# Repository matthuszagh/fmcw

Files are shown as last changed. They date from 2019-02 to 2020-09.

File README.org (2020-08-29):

#+NAME: fig:bridge raw-fft
#+ATTR_ORG: :width 1000
#+ATTR_HTML: :width 100%
[[file:data/bridge_raw.png][file:.img/bridge_raw.png]]

Real-time range detection performed by radar. Distance (y-axis) is in
meters and the time (x-axis) is in seconds. Magnitude is in dBFS
relative to the max ADC input.

* Table of Contents
1. [[https://github.com/matthuszagh/fmcw#about][About]]
2. [[https://github.com/matthuszagh/fmcw#capabilities][Capabilities]]
3. [[https://github.com/matthuszagh/fmcw#installation][Installation]]
4. [[https://github.com/matthuszagh/fmcw#usage][Usage]]
5. [[https://github.com/matthuszagh/fmcw#additional-hardware][Additional Hardware]]
6. [[https://github.com/matthuszagh/fmcw#contributing][Contributing]]
7. [[https://github.com/matthuszagh/fmcw#thanks][Thanks]]

* About
:PROPERTIES:
:ID:       20ff1c28-cfc6-4280-8501-83314fee390d
:END:
This repo includes the custom PCBs, PC control software and FPGA
gateware necessary to build and operate a 6GHz FMCW radar. It also
includes a number of other useful additions, such as RF and SPICE
simulations (in progress) as well as CAD designs for useful additions
(e.g. to build the horn antennas).

The project is a fork of [[https://github.com/Ttl/fmcw3][Henrik's excellent design]]. Although I've made
a number of [[id:8f78da8c-ec0c-40f3-9b8b-6c1af11f4bb2][significant changes]], most of the PCB design (as of this
writing) is still identical to Henrik's. Despite the fact that Henrik
deserves a large share of the credit for this project, he is in no way
affiliated with this fork.

This project is still a work in progress. While [[https://github.com/matthuszagh/fmcw/tree/master/hardware/boards/rev1][rev1]] achieves good
results, the noise floor is higher than it should be. In particular,
this version suffers from an excessively noisy switching
converter. [[https://github.com/matthuszagh/fmcw/tree/master/hardware/boards/rev2][Rev2]] has been designed to fix these issues, but still
requires a few changes before it's ready to be built. In the meantime,
if you're able to track down the power amplifier Henrik used in his
design (it's deprecated, but some people have had luck on Ebay), I
would recommend that over rev1.

* Capabilities
This radar (and associated software) can display the range of remote
objects in real-time out to at least 250m. The radar should be capable
of ranges up to 1km, but this has not yet been tested. The radar code
is also designed to be quite flexible. For instance, you can display
data at any intermediary processing step (including the raw receiver
channel data) without recompiling the FPGA code. All display
configurations support real-time plotting. The many configuration
options can be viewed by invoking the software shell environment (see
[[https://github.com/matthuszagh/fmcw#usage][usage]])

The PCB is capable of angle detection as well, but the associated FPGA
and software code has not yet been written to support this. A future
update will also add an RF switch to multiplex the receiver channels
for better angular resolution.

* Installation
:PROPERTIES:
:ID:       fe23bc7f-9bcf-4526-9d7e-bded4078111d
:END:
Using the radar requires an installation of [[https://sourceforge.net/projects/openocd/][OpenOCD]] (for loading the
bitstream onto the FPGA), [[https://www.intra2net.com/en/developer/libftdi/][libFTDI1]] for communicating between the host
Linux machine and the radar and a Python3 installation including
[[https://numpy.org/][NumPy]], [[https://www.scipy.org/][SciPy]], [[http://www.pyqtgraph.org/][PyQtGraph]], as well as a [[https://cython.org/][Cython compiler]] to compile a
small amount of optimized C code.

Finally, it is necessary to have unprivileged access to the radar in
order to use it. Add the following to ~/etc/udev~ (for instance, in
~/etc/udev/rules.d/99-local.rules~):

#+begin_src txt
# FMCW Radar
ENV{ID_VENDOR_ID}=="0403", ENV{ID_MODEL_ID}=="6010", MODE:="666"
#+end_src

To register the changes, run:

#+begin_src sh
sudo udevadm control --reload-rules && udevadm trigger
#+end_src

** FPGA Bitstream Generation
The FPGA bitstream is updated in this repo whenever the Verilog code
changes. As a result, if you just want to use the radar you should
never need to compile the bitstream yourself. If you do want to modify
the FPGA configuration, you can edit the Verilog source files to your
liking (located in [[https://github.com/matthuszagh/fmcw/tree/master/gateware/verilog/src][gateware/verilog/src]]) and then recompile the
bitstream with ~make bitstream~ in the [[https://github.com/matthuszagh/fmcw/tree/master/gateware/verilog][gateware/verilog]]
directory. This requires an installation of Vivado. I've only tested
this with v2017.2, although it should work with newer versions as
well. If this is not the case please file a bug report.

** Tests and Formal Verification
Verilog functional tests and formal verification can be run from
[[https://github.com/matthuszagh/fmcw/tree/master/gateware/verilog][gateware/verilog]] directory with ~make test~ (for [[https://docs.cocotb.org/en/latest/][Cocotb]] tests), ~make
sim~ for more traditional Verilog testbenches, and ~make formal~ for
formal verification. There are also subtargets for specific
modules. Cocotb tests require an installation of Cocotb and
traditional Verilog testbenches require an installation of [[https://github.com/steveicarus/iverilog][Icarus
Verilog]]. Formal verification requires [[https://github.com/YosysHQ/SymbiYosys][SymbiYosys]], [[https://github.com/YosysHQ/yosys][yosys]], and the [[https://github.com/SRI-CSL/yices2][yices]]
SMT solver.

** Microwave Simulations
Microwave simulations are performed with [[https://openems.de/start/][OpenEMS]], using my own python
interface tool, [[https://github.com/matthuszagh/pyems][pyems]]. These are located in the [[https://github.com/matthuszagh/fmcw/tree/master/simulations/openems][simulations/openems]]
directory and can be run individually.

** Ngspice Simulations
Ngspice simulations are a work-in-progress. Nevertheless, if you'd
like to test them they can be found in the [[https://github.com/matthuszagh/fmcw/tree/master/simulations/ngspice][simulations/ngspice]]
directory and the python files can be run individually. They require
an installation of [[https://github.com/xesscorp/skidl][SKiDL]], [[https://github.com/FabriceSalvaire/PySpice][PySpice]], and, of course, [[http://ngspice.sourceforge.net/][Ngspice]].

** CAD Designs
The antenna mount and horn antenna CAD designs are available in the
[[https://github.com/matthuszagh/fmcw/tree/master/hardware/cad][hardware/cad]] directory. The [[https://www.openscad.org/][OpenSCAD]] source files as well as the
generated STL files are available there. If you only want to 3D print
the objects, the STL files are sufficient. If, however, you'd like to
modify them, you'll need an installation of OpenSCAD (or you can
modify the STL files in another CAD program like FreeCAD).

** PCB Design
The KiCAD PCB design files are located in subdirectories of
[[https://github.com/matthuszagh/fmcw/tree/master/hardware/boards][hardware/boards]]. They require KiCAD to view and modify. The gerbers
are available as zip files here. Note that because rev2 is not yet
complete, those gerbers are not up-to-date. The hardware directory
also contains some projects which are in development, such as an
antenna switch and various prototype boards. These are not, in
general, complete and are thus not recommended for use.

* Usage
When the radar is setup and plugged in, administer power to the PCB,
navigate to the top-level directory and type ~make~. This will program
the bitstream to the FPGA and invoke a custom shell for interacting
with the radar. If everything so far has worked, you will be presented
with the following shell environment:

#+begin_example
Available commands:
----------
conf : Display current configuration.
exit : Exit.
help : This display.
run  : Instantiate the current configuration,
       begin data acquisition, and display output.
set  : Change the value of a configuration
       variable.
menu : Automatically set configuration variables
       based on one of several common tasks.

fmcw >
#+end_example

We can redisplay this menu at any point by typing ~fmcw > help~
(~fmcw >~ is prompted as part of the shell display, so you only need to
type ~help~), and we can exit with ~fmcw > exit~.

The set of possible commands appears in the left column, with their
associated descriptions to the right. All commands can be typed
exactly as displayed, or you can type the minimum number of letters
that uniquely differentiates a menu entry from the other entries. So,
for instance, if I wanted to see the current configuration I could
type ~fmcw > c~ (~conf~ is the only command that begins with the
letter ~c~).

#+begin_example
fmcw > c
Configuration:
----------
FPGA output                 : RAW
display output              : FFT
log file                    : /home/matt/src/fmcw/software
capture time (s)            : 35
plot type                   : HIST
dB min                      : -120.0
dB max                      : -20.0
plot save dir               : /home/matt/src/fmcw/software/plots
subtract last               : True
receiver channel            : B
ADF start frequency (Hz)    : 5600000000.0
ADF bandwidth (Hz)          : 300000000.0
ADF sweep time (s)          : 0.001
ADF delay time (s)          : 0.002
min plotting frequency (Hz) : 0
max plotting frequency (Hz) : 470325
min plotting distance (m)   : 0
max plotting distance (m)   : 235
dist/freq axis              : dist
report average              : False
#+end_example

If I wanted to view, say, a spectrum plot instead of a histogram, I
would start by typing ~fmcw > s~.

This presents the configuration options

#+begin_example
fmcw > set
Set options (enter the corresponding number):
----------
0. FPGA output
1. display output
2. log file
3. capture time (s)
4. plot type
5. dB min
6. dB max
7. plot save dir
8. subtract last
9. receiver channel
10. ADF start frequency (Hz)
11. ADF bandwidth (Hz)
12. ADF sweep time (s)
13. ADF delay time (s)
14. min plotting frequency (Hz)
15. max plotting frequency (Hz)
16. min plotting distance (m)
17. max plotting distance (m)
18. dist/freq axis
19. report average
#+end_example

Since I wanted to change ~plot type~, which is entry 4, I'd type ~set
> 4~,

#+begin_example
set > 4
Parameter       : plot type
Current Value   : HIST
Possible Values : {TIME (except FFT output), SPECTRUM, HIST} (case insensitive)

**Note that when setting selection options (e.g. plot type),
it is only necessary to type the first characters that fully
differentiate the selection from all other choices.
#+end_example

This tells me the available selections for this parameter. Like
before, I'm allowed to just type the first differentiating letters,
which in this case is simpy ~new value > s~

#+begin_example
new value > s
New value set.
#+end_example

which presents a comfirmation that the value has been correctly
set. Indeed, if we redisplay the current configuration, we see that
plot type is now SPECTRUM:

#+begin_example
fmcw > conf
Configuration:
----------
FPGA output                 : RAW
display output              : FFT
log file                    : /home/matt/src/fmcw/software
capture time (s)            : 35
plot type                   : SPECTRUM
dB min                      : -120.0
dB max                      : -20.0
plot save dir               : /home/matt/src/fmcw/software/plots
subtract last               : True
receiver channel            : B
ADF start frequency (Hz)    : 5600000000.0
ADF bandwidth (Hz)          : 300000000.0
ADF sweep time (s)          : 0.001
ADF delay time (s)          : 0.002
min plotting frequency (Hz) : 0
max plotting frequency (Hz) : 470325
min plotting distance (m)   : 0
max plotting distance (m)   : 235
dist/freq axis              : dist
report average              : False
#+end_example

Tweaking all of these values can become a bit tedius, so the shell can
conveniently set all values for a number of commonly-needed
setups. For instance, imagine we'd like to measure the receiver noise
floor. We can select the menu option, ~fmcw > m~.

#+begin_example
fmcw > menu
Menu options (enter the corresponding number):
----------
0. Range Plot (235m)
1. Noise Floor
#+end_example

This currently just provides two configurations, but the list will
grow over time. We'd select ~fmcw > 1~. Now, if we view the
configuration we will see that many values have been updated. Indeed,
this is precisely the configuration we want to compute the noise floor
(if you're following along, make sure you've terminated your
transmission and reception ports with 50ohm loads before proceeding).

#+begin_example
fmcw > conf
Configuration:
----------
FPGA output                 : RAW
display output              : RAW
log file                    : /home/matt/src/fmcw/software
capture time (s)            : 10
plot type                   : SPECTRUM
dB min                      : -120.0
dB max                      : -20.0
plot save dir               : /home/matt/src/fmcw/software
subtract last               : False
receiver channel            : B
ADF start frequency (Hz)    : 5600000000.0
ADF bandwidth (Hz)          : 300000000.0
ADF sweep time (s)          : 0.001
ADF delay time (s)          : 0.002
min plotting frequency (Hz) : 50000
max plotting frequency (Hz) : 1000000
min plotting distance (m)   : 24
max plotting distance (m)   : 499
dist/freq axis              : freq
report average              : True
#+end_example

Finally, when we're satisfied with the configuration we can type ~fmcw
> r~ (run), which will perform additional FPGA configuration and begin
acquiring and plotting data. The configuration settings specify a
capture time. Currently, it is set to 10s. So, after 10s the plot will
end and we will be represented with the prompt.

* Additional Hardware
The KiCAD PCB files contain a full BOM of components needed to build
the circuit board. You will, of course, need a way to assemble it (or
you can have a 3rd party assemble the board for you). This design
contains a lot of small components. Therefore, I highly recommend you
use a reflow process if you intend to assemble this yourself.

The PCB board requires a 12V DC power supply (it is not
USB-powered). Also ensure you get the right size barrel jack connector
for the port. A USB cable is required to connect to a host PC. A gen2
cable is sufficient because the PCB USB chip does not support
gen3. Similarly, the host PC should support at least USB 2.0 High
Speed. Otherwise, this may limit the realtime performance of your
radar.

The radar requires at least 2 antennas to operate. The choice of
antennas is up to you, but you should at least make sure that their
bandwidth includes the 5.3 to 5.9GHz range. I'm using [[https://antennatestlab.com/3dprinting][3D-printed]] horn
antennas, which work quite well. If you'd like to take full advantage
of the radar's range, the horn antennas are a good choice because they
have a high directivity. The design files to print these are included
in the CAD designs of this repo. If your 3D printer does not support
the z height, you can print the antenna in 2 parts and then glue the
parts together. Finally, if you're using the horn antennas you'll
additionally need WR159 waveguide-coax adapters. These can be picked
up on Ebay or other similar sites. The ones I purchased were $60
each. The PCB uses SMA connectors, so if the waveguide coax port is
not SMA you will additionally need an adapter for that (or an
asymmetric cable that supports the port it uses). Painting the
antennas require a number of other materials specified in the link
above. I personally achieved a better result using a traditional paint
jar than the recommended spray paint, but either should work. Another
option which I haven't tried but could work is coating the antenna in
copper foil.

* Contributing
Pull requests and issues welcome. I'm open to suggestions for hardware
modification, although may or may not be able to merge those commits
depending on whether I can test the change.

* Thanks
+ Henrik, of course (see [[id:20ff1c28-cfc6-4280-8501-83314fee390d][About]]).
+ An additional thanks to AlexBdx for finding a way to 3D print horn
  antennas.

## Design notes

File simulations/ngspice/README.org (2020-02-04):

Many of the spice simulations in this directory use vendor-distributed
models. I've set up the simulations to look for these models in the
SPICELIB environment variable. In order to run these simulations,
you'll need to track down the models from vendor websites and place
them in some subdirectory of the directory pointed to by SPICELIB.

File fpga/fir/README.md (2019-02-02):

#### fir.m

Octave file that computes the impulse response for a digital filter with the specified number of
taps, passband and stopband regions, etc. It then saves the filter taps to `fir_coeffs.dbl` and the
frequency response plot to `fir.svg`.

#### dbl_to_hex.py

Quantizes the FIR impulse response double coefficients to integral values for a specified bit
width. The default value is 16 bits. The quantization error for a range of bit widths can be
computed with `quantization_cost.py`. The quantized filter coefficients are saved to `taps.hex`.

#### Makefile

Run `make` to create the FIR filter with default settings.

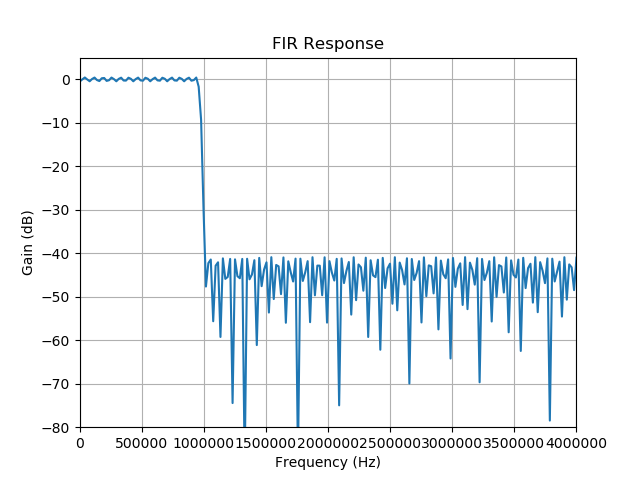
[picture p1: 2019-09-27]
fpga/fir/plot_response.png

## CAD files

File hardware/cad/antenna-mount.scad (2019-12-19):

// plane
plane_x = 310;
plane_y = 210;
plane_z = 6.35;

diff_pad = 0.5;

// support
sup_x = plane_z;
sup_y = 50;
sup_z = 150;
wave_sup_ysep = 30;

// support joint
sup_jt_x = 5 * sup_x;
sup_jt_y = sup_y;
sup_jt_z = sup_z / 5;

// waveguide base
wave_base_x = 81;
wave_base_y = 62;

// waveguide
wave_x = 45;
wave_y = 25;
wave_insert_y = wave_y + 10;
wave_z = plane_z + 2 * diff_pad;
wave_sep = 190;
wave_offx = 60;
wave_offy = sup_y + wave_sup_ysep + (wave_base_y / 2);

// antenna screw holes
hole_diam = 6.5;
right_hole_offy = 19.1 / 2;
right_hole_offx = 64.7 / 2;
top_hole_offx = 25.4 / 2;
top_hole_offy = 44.5 / 2;

// pcb screw holes
pcb_hole_diam = 3.7;
pcb_xsep = 51;
pcb_small_ysep = 2.5;
pcb_large_ysep = 110.5;
pcb_xtra_yoff = 35;

function pt_from_mid(mid, dim) = mid - (dim / 2);

union()
{
	translate([ pt_from_mid(wave_offx / 2, sup_x), 0, 0 ]) { cube([ sup_x, sup_y, sup_z ]); }
	translate([ pt_from_mid(wave_offx / 2, sup_jt_x), 0, 0 ])
	{
		cube([ sup_jt_x, sup_jt_y, sup_jt_z ]);
	}
	translate([ pt_from_mid(plane_x - (wave_offx / 2), sup_x), 0, 0 ])
	{
		cube([ sup_x, sup_y, sup_z ]);
	}
	translate([ pt_from_mid(plane_x - (wave_offx / 2), sup_jt_x), 0, 0 ])
	{
		cube([ sup_jt_x, sup_jt_y, sup_jt_z ]);
	}
	difference()
	{
		// plane
		translate([ 0, 0, 0 ]) { cube([ plane_x, plane_y, plane_z ]); }
		// left waveguide slot
		translate([
			pt_from_mid(wave_offx, wave_x), pt_from_mid(wave_offy, wave_y), -diff_pad
		])
		{
			cube([ wave_x, wave_y, wave_z ]);
		}
		translate([ 0, pt_from_mid(wave_offy, wave_insert_y), -diff_pad ])
		{
			cube([ wave_offx - (wave_x / 2), wave_insert_y, wave_z ]);
		}
		// right waveguide slot
		translate([
			pt_from_mid(plane_x - wave_offx, wave_x), pt_from_mid(wave_offy, wave_y), -
			diff_pad
		])
		{
			cube([ wave_x, wave_y, wave_z ]);
		}
		translate([
			plane_x - (wave_offx - (wave_x / 2)), pt_from_mid(wave_offy, wave_insert_y),
			-diff_pad
		])
		{
			cube([ wave_offx - (wave_x / 2), wave_insert_y, wave_z ]);
		}
		// antenna mount screw holes
		// left side
		translate([ wave_offx - top_hole_offx, wave_offy + top_hole_offy, -diff_pad ])
		{
			cylinder(h = plane_z + 2 * diff_pad, d = hole_diam, $fn = 100);
		}
		translate([ wave_offx + top_hole_offx, wave_offy + top_hole_offy, -diff_pad ])
		{
			cylinder(h = plane_z + 2 * diff_pad, d = hole_diam, $fn = 100);
		}
		translate([ wave_offx - top_hole_offx, wave_offy - top_hole_offy, -diff_pad ])
		{
			cylinder(h = plane_z + 2 * diff_pad, d = hole_diam, $fn = 100);
		}
		translate([ wave_offx + top_hole_offx, wave_offy - top_hole_offy, -diff_pad ])
		{
			cylinder(h = plane_z + 2 * diff_pad, d = hole_diam, $fn = 100);
		}
		translate([ wave_offx + right_hole_offx, wave_offy + right_hole_offy, -diff_pad ])
		{
			cylinder(h = plane_z + 2 * diff_pad, d = hole_diam, $fn = 100);
		}
		translate([ wave_offx + right_hole_offx, wave_offy - right_hole_offy, -diff_pad ])
		{
			cylinder(h = plane_z + 2 * diff_pad, d = hole_diam, $fn = 100);
		}
		// right side
		translate([
			plane_x - (wave_offx - top_hole_offx), wave_offy + top_hole_offy, -diff_pad
		])
		{
			cylinder(h = plane_z + 2 * diff_pad, d = hole_diam, $fn = 100);
		}
		translate([
			plane_x - (wave_offx + top_hole_offx), wave_offy + top_hole_offy, -diff_pad
		])
		{
			cylinder(h = plane_z + 2 * diff_pad, d = hole_diam, $fn = 100);
		}
		translate([
			plane_x - (wave_offx - top_hole_offx), wave_offy - top_hole_offy, -diff_pad
		])
		{
			cylinder(h = plane_z + 2 * diff_pad, d = hole_diam, $fn = 100);
		}
		translate([
			plane_x - (wave_offx + top_hole_offx), wave_offy - top_hole_offy, -diff_pad
		])
		{
			cylinder(h = plane_z + 2 * diff_pad, d = hole_diam, $fn = 100);
		}
		translate([
			plane_x - (wave_offx + right_hole_offx), wave_offy + right_hole_offy, -
			diff_pad
		])
		{
			cylinder(h = plane_z + 2 * diff_pad, d = hole_diam, $fn = 100);
		}
		translate([
			plane_x - (wave_offx + right_hole_offx), wave_offy - right_hole_offy, -
			diff_pad
		])
		{
			cylinder(h = plane_z + 2 * diff_pad, d = hole_diam, $fn = 100);
		}
		// pcb screw holes
		translate([
			(plane_x / 2) - (pcb_xsep / 2),
			pcb_xtra_yoff + (plane_y / 2) - (pcb_large_ysep / 2), -diff_pad
		])
		{
			cylinder(h = plane_z + 2 * diff_pad, d = pcb_hole_diam, $fn = 100);
		}
		translate([
			(plane_x / 2) - (pcb_xsep / 2),
			pcb_xtra_yoff + (plane_y / 2) + (pcb_large_ysep / 2), -diff_pad
		])
		{
			cylinder(h = plane_z + 2 * diff_pad, d = pcb_hole_diam, $fn = 100);
		}
		translate([
			(plane_x / 2) + (pcb_xsep / 2),
			pcb_xtra_yoff + (plane_y / 2) + (pcb_large_ysep / 2) - pcb_small_ysep, -
			diff_pad
		])
		{
			cylinder(h = plane_z + 2 * diff_pad, d = pcb_hole_diam, $fn = 100);
		}
	}
}

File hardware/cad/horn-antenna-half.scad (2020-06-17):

base_width = 81.0;
base_height = 62.0;
base_thickness = 6.35;
hole_diam = 6.5;
right_hole_y_offset = 19.1 / 2;
right_hole_x_offset = 64.7 / 2;
top_hole_x_offset = 25.4 / 2;
top_hole_y_offset = 44.5 / 2;
flange_width = 40.39;
flange_height = 20.19;
thickness = 5;
sec1_length = 2 * base_thickness;
sec2_width = 110.0;
sec2_height = 80.0;
sec2_zmax = 203.2;

difference()
{
	union()
	{
		// base
		difference()
		{
			// base
			translate([ -base_width / 2, -base_height / 2, 0 ])
			{
				cube([ base_width, base_height, base_thickness ]);
			}
			// top and bottom screw holes
			translate([ -top_hole_x_offset, -top_hole_y_offset, -0.1 ])
			{
				cylinder(h = base_thickness + 0.2, d = hole_diam, $fn = 100);
			}
			translate([ -top_hole_x_offset, top_hole_y_offset, -0.1 ])
			{
				cylinder(h = base_thickness + 0.2, d = hole_diam, $fn = 100);
			}
			translate([ top_hole_x_offset, top_hole_y_offset, -0.1 ])
			{
				cylinder(h = base_thickness + 0.2, d = hole_diam, $fn = 100);
			}
			translate([ top_hole_x_offset, -top_hole_y_offset, -0.1 ])
			{
				cylinder(h = base_thickness + 0.2, d = hole_diam, $fn = 100);
			}
			// left and right screw holes
			translate([ right_hole_x_offset, right_hole_y_offset, -0.1 ])
			{
				cylinder(h = base_thickness + 0.2, d = hole_diam, $fn = 100);
			}
			translate([ -right_hole_x_offset, right_hole_y_offset, -0.1 ])
			{
				cylinder(h = base_thickness + 0.2, d = hole_diam, $fn = 100);
			}
			translate([ right_hole_x_offset, -right_hole_y_offset, -0.1 ])
			{
				cylinder(h = base_thickness + 0.2, d = hole_diam, $fn = 100);
			}
			translate([ -right_hole_x_offset, -right_hole_y_offset, -0.1 ])
			{
				cylinder(h = base_thickness + 0.2, d = hole_diam, $fn = 100);
			}
			// flange
			translate([ -flange_width / 2, -flange_height / 2, -0.1 ])
			{
				cube([ flange_width, flange_height, base_thickness + 0.2 ]);
			}
		}

		// section 1
		difference()
		{
			translate([
				-flange_width / 2 - thickness, -flange_height / 2 - thickness,
				base_thickness
			])
			{
				cube([
					flange_width + 2 * thickness, flange_height + 2 * thickness,
					sec1_length
				]);
			}
			translate([ -flange_width / 2, -flange_height / 2, base_thickness - 0.1 ])
			{
				cube([ flange_width, flange_height, sec1_length + 0.2 ]);
			}
		}

		// section 2
		points_outer = [
			[
				-flange_width / 2 - thickness, -flange_height / 2 - thickness,
				base_thickness +
				sec1_length
			],
			[
				-flange_width / 2 - thickness, flange_height / 2 + thickness,
				base_thickness +
				sec1_length
			],
			[
				flange_width / 2 + thickness, flange_height / 2 + thickness,
				base_thickness +
				sec1_length
			],
			[
				flange_width / 2 + thickness, -flange_height / 2 - thickness,
				sec1_length +
				base_thickness
			],
			[ -sec2_width / 2 - thickness, -sec2_height / 2 - thickness, sec2_zmax ],
			[ -sec2_width / 2 - thickness, sec2_height / 2 + thickness, sec2_zmax ],
			[ sec2_width / 2 + thickness, sec2_height / 2 + thickness, sec2_zmax ],
			[ sec2_width / 2 + thickness, -sec2_height / 2 - thickness, sec2_zmax ]
		];

		points_inner = [
			[ -flange_width / 2, -flange_height / 2, base_thickness + sec1_length ],
			[ -flange_width / 2, flange_height / 2, base_thickness + sec1_length ],
			[ flange_width / 2, flange_height / 2, base_thickness + sec1_length ],
			[ flange_width / 2, -flange_height / 2, base_thickness + sec1_length ],
			[ -sec2_width / 2, -sec2_height / 2, sec2_zmax ],
			[ -sec2_width / 2, sec2_height / 2, sec2_zmax ],
			[ sec2_width / 2, sec2_height / 2, sec2_zmax ],
			[ sec2_width / 2, -sec2_height / 2, sec2_zmax ]
		];

		difference()
		{
			polyhedron(points_outer, faces = [
				[ 0, 4, 7, 3 ], [ 1, 5, 4, 0 ], [ 2, 6, 5, 1 ], [ 3, 7, 6, 2 ],
				[ 3, 2, 1, 0 ], [ 4, 5, 6, 7 ]
			]);
			polyhedron(points_inner, faces = [
				[ 3, 7, 4, 0 ], [ 0, 4, 5, 1 ], [ 1, 5, 6, 2 ], [ 2, 6, 7, 3 ],
				[ 0, 1, 2, 3 ], [ 7, 6, 5, 4 ]
			]);
		}
	}
	rotate([ 0, 0, atan(sec2_height / sec2_width) ])
	{
		translate([ -2 * sqrt(pow(sec2_width, 2) + pow(sec2_height, 2)) / 2, 0, 0 ])
		{
			cube([
				2 * sqrt(pow(sec2_width, 2) + pow(sec2_height, 2)), sec2_width,
				sec2_zmax
			]);
		}
	}
}

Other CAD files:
hardware/cad/antenna-mount.stl
hardware/cad/horn-antenna.stl
hardware/cad/horn-antenna.scad

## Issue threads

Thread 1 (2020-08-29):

allow programming spi flash so that fpga loads bitstream on startup

matthuszagh, 2020-08-29:
This can be accomplished with migen and openocd using the scripts [here](https://github.com/quartiq/bscan_spi_bitstreams). This is what Henrik used. Alternatively, the flash device could be swapped for another which supports programming directly from Vivado (see appendix C of the Design Suite User Guide: Programming and Debugging). Swapping the flash device has the benefit of supporting both of these methods.

Closed 2020-09-03.

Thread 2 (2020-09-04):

Verify coupler performance with VNA

matthuszagh, 2020-09-04:
The actual coupler performance seems to be suboptimal. We should verify this with a VNA (and preferably justify it with a tolerance analysis using [pyems](https://github.com/matthuszagh/pyems). If performance is too bad, it may be necessary to use an IC instead.

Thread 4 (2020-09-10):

Replace Wilkinson divider and attenuators with resistive power splitter

matthuszagh, 2020-09-10:

Closed 2020-09-12.

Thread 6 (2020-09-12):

power amp heat dissipation

matthuszagh, 2020-09-12:
The power amplifier gets very hot, although the exact max temperature is
unknown. Consider getting an IR camera to actually measure it. More
importantly, though, thermal management of the component land pattern
should be improved. All of the following improvements come from the
suggested land pattern in the datasheet.

1. Use 25 vias (5x5) spaced 0.5mm apart. They should be tented on the
   backside and filled with solder. The vias should not use thermal
   reliefs. Set pad connection to solid.
2. Exposed pad should connect directly to the coplanar ground plane
   (set pad connection to solid). See the image in the datasheet. Many
   of the component pins are ground pins which should be attached
   directly to the exposed pad and coplanar ground plane.
3. Ensure sufficient ground planes beneath component. The second layer
   is an unbroken ground plane, which is good. The 3rd layer is a
   power plane. Maybe this should be made a ground plane below the
   power amp? 4th layer connection to ground plane should be fixed by
   setting pad connection to solid I think?
4. Remove solder mask from the back side (directly behind the PA) and
   attach a heatsink there. [[https://www.digikey.com/product-detail/en/wakefield-vette/LTN20069/345-1101-ND/1644633][This heatsink]] looks good. This will mean
   that you can't tent the vias. That should be fine. And anyway, if
   you solder the backside first, you should still be able to fill the
   vias. That might prevent the top side from reflowing though, and
   may be worse than just not filling the vias. I think the best is to
   remove the soldermask from the backside and use the adhesive tape
   rather than solder to connect the heatsink. Apparently, solder
   isn't very thermally conductive anyway.

Closed 2020-09-12.

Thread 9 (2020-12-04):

Coupler should maybe be implemented on internal layer

matthuszagh, 2020-12-04:
Coupler performance is typically better on an internal PCB layer than an external layer. Simulate and measure performance on a VNA.

Also worth checking the effect of soldermask when implemented on an external layer.

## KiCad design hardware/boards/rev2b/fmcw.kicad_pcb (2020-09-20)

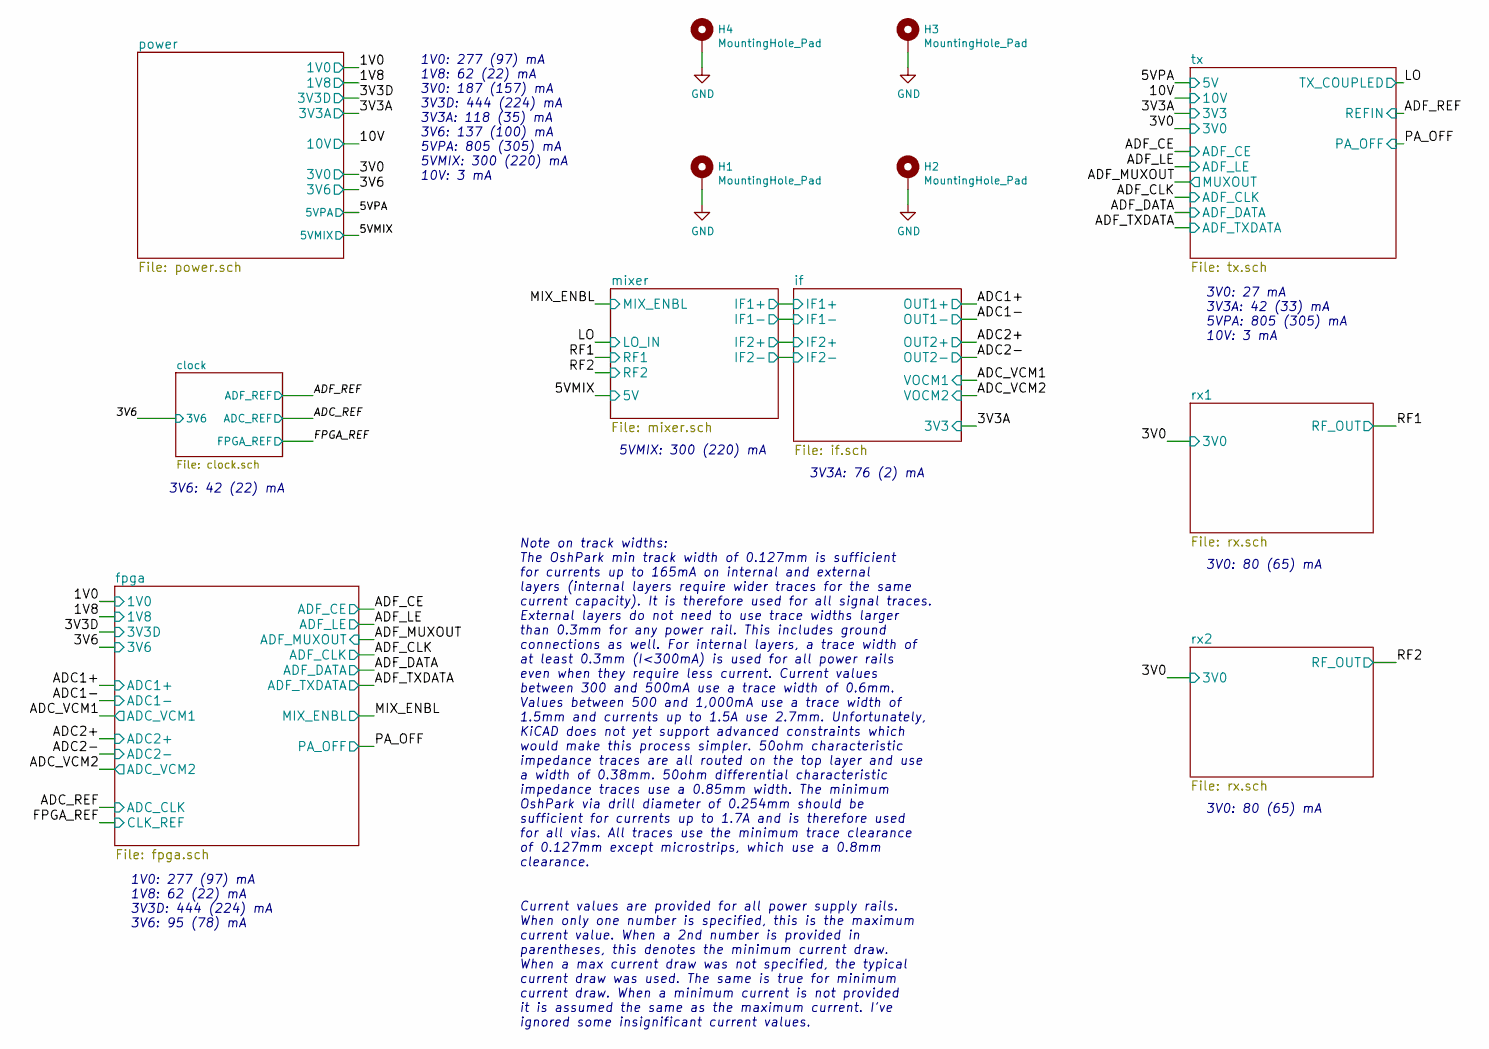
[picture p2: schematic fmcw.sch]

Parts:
H1, H2, H3, H4: MountingHole_Pad; MountingHole_3.2mm_M3_Pad_Via

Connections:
GND: H1.1, H2.1, H3.1, H4.1; also elsewhere on the board

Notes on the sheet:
1V0: 277 (97) mA 1V8: 62 (22) mA 3V3D: 444 (224) mA 3V6: 95 (78) mA
3V6: 42 (22) mA
1V0: 277 (97) mA 1V8: 62 (22) mA 3V0: 187 (157) mA 3V3D: 444 (224) mA 3V3A: 118 (35) mA 3V6: 137 (100) mA 5VPA: 805 (305) mA 5VMIX: 300 (220) mA 10V: 3 mA
Note on track widths: The OshPark min track width of 0.127mm is sufficient for currents up to 165mA on internal and external layers (internal layers require wider traces for the same current capacity). It is therefore used for all signal traces. External layers do not need to use trace widths large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
Current values are provided for all power supply rails. When only one number is specified, this is the maximum current value. When a 2nd number is provided in parentheses, this denotes the minimum current draw. When a max current draw was not specified, the typical current draw was used. The same i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
5VMIX: 300 (220) mA
3V3A: 76 (2) mA
3V0: 27 mA 3V3A: 42 (33) mA 5VPA: 805 (305) mA 10V: 3 mA
3V0: 80 (65) mA

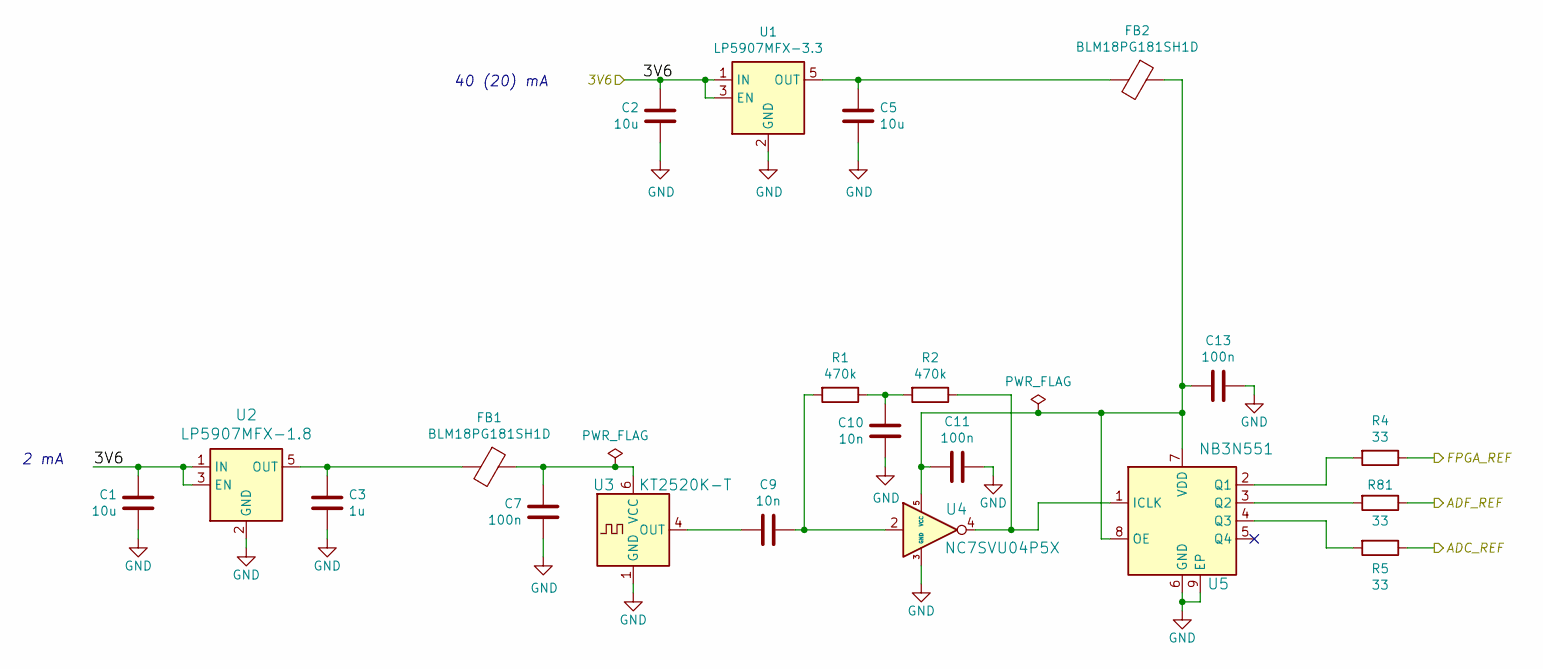
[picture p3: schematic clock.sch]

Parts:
C1, C2, C5: 10u; C_0805_2012Metric
C3: 1u; C_0805_2012Metric
C7, C11, C13: 100n; C_0402_1005Metric
C9, C10: 10n; C_0402_1005Metric
FB1, FB2: BLM18PG181SH1D; L_0603_1608Metric
R1, R2: 470k; R_0402_1005Metric
R4, R5, R81: 33; R_0402_1005Metric
U1: LP5907MFX-3.3; SOT-23-5
U2: LP5907MFX-1.8; SOT-23-5
U3: KT2520K-T; Oscillator_SMD_Kyocera_2520-6Pin_2.5x2.0mm
U4: NC7SVU04P5X; SOT-353_SC-70-5
U5: NB3N551; DFN-8-1EP_2x2mm_P0.5mm_EP0.9x1.3mm

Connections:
/3V6: C1.1, C2.1, U1.1 (IN), U1.3 (EN), U2.1 (IN), U2.3 (EN); also elsewhere on the board
/ADC_REF: R5.1; also elsewhere on the board
/ADF_REF: R81.1; also elsewhere on the board
/FPGA_REF: R4.1; also elsewhere on the board
GND: C1.2, C2.2, C3.2, C5.2, C7.1, C10.1, C11.1, C13.1, U1.2 (GND), U2.2 (GND), U3.1 (GND), U3.3 (GND), U4.3 (GND), U5.6 (GND), U5.9 (EP); also elsewhere on the board
unnamed: C3.1, FB1.2, U2.5 (OUT)
unnamed: C5.1, FB2.2, U1.5 (OUT)
unnamed: C7.2, FB1.1, U3.6 (VCC)
unnamed: C9.1, R1.2, U4.2
unnamed: C9.2, U3.4 (OUT)
unnamed: C10.2, R1.1, R2.2
unnamed: C11.2, C13.2, FB2.1, U4.5 (VCC), U5.7 (VDD), U5.8 (OE)
unnamed: R2.1, U4.4, U5.1 (ICLK)
unnamed: R4.2, U5.2 (Q1)
unnamed: R5.2, U5.4 (Q3)
unnamed: R81.2, U5.3 (Q2)

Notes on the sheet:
2 mA
40 (20) mA

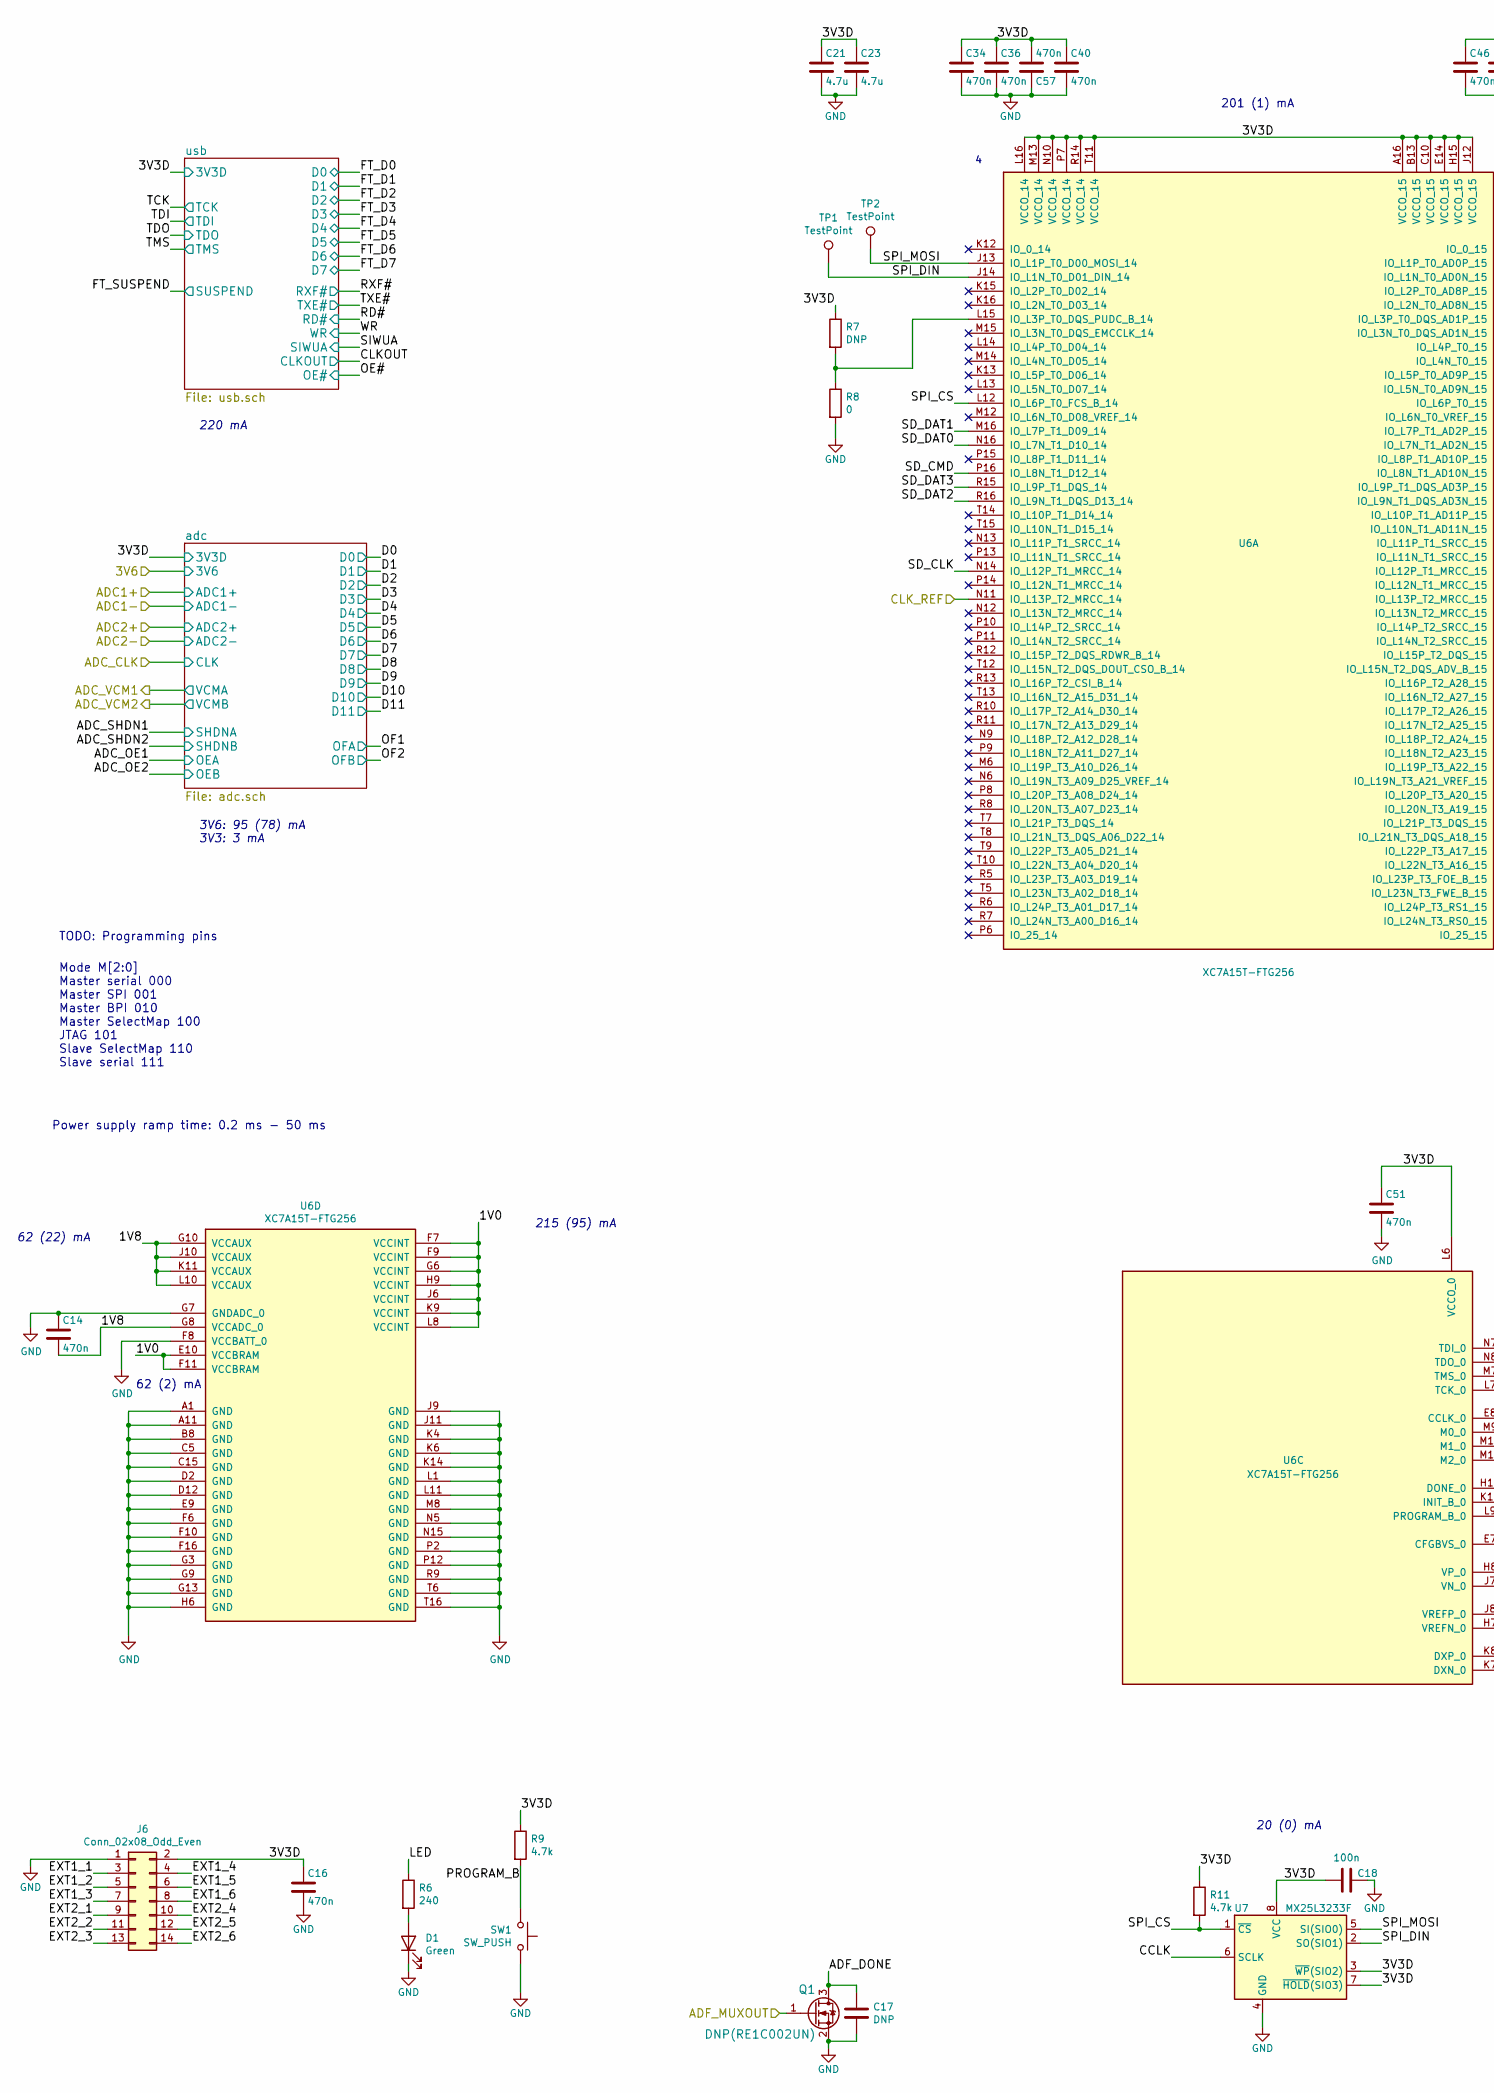
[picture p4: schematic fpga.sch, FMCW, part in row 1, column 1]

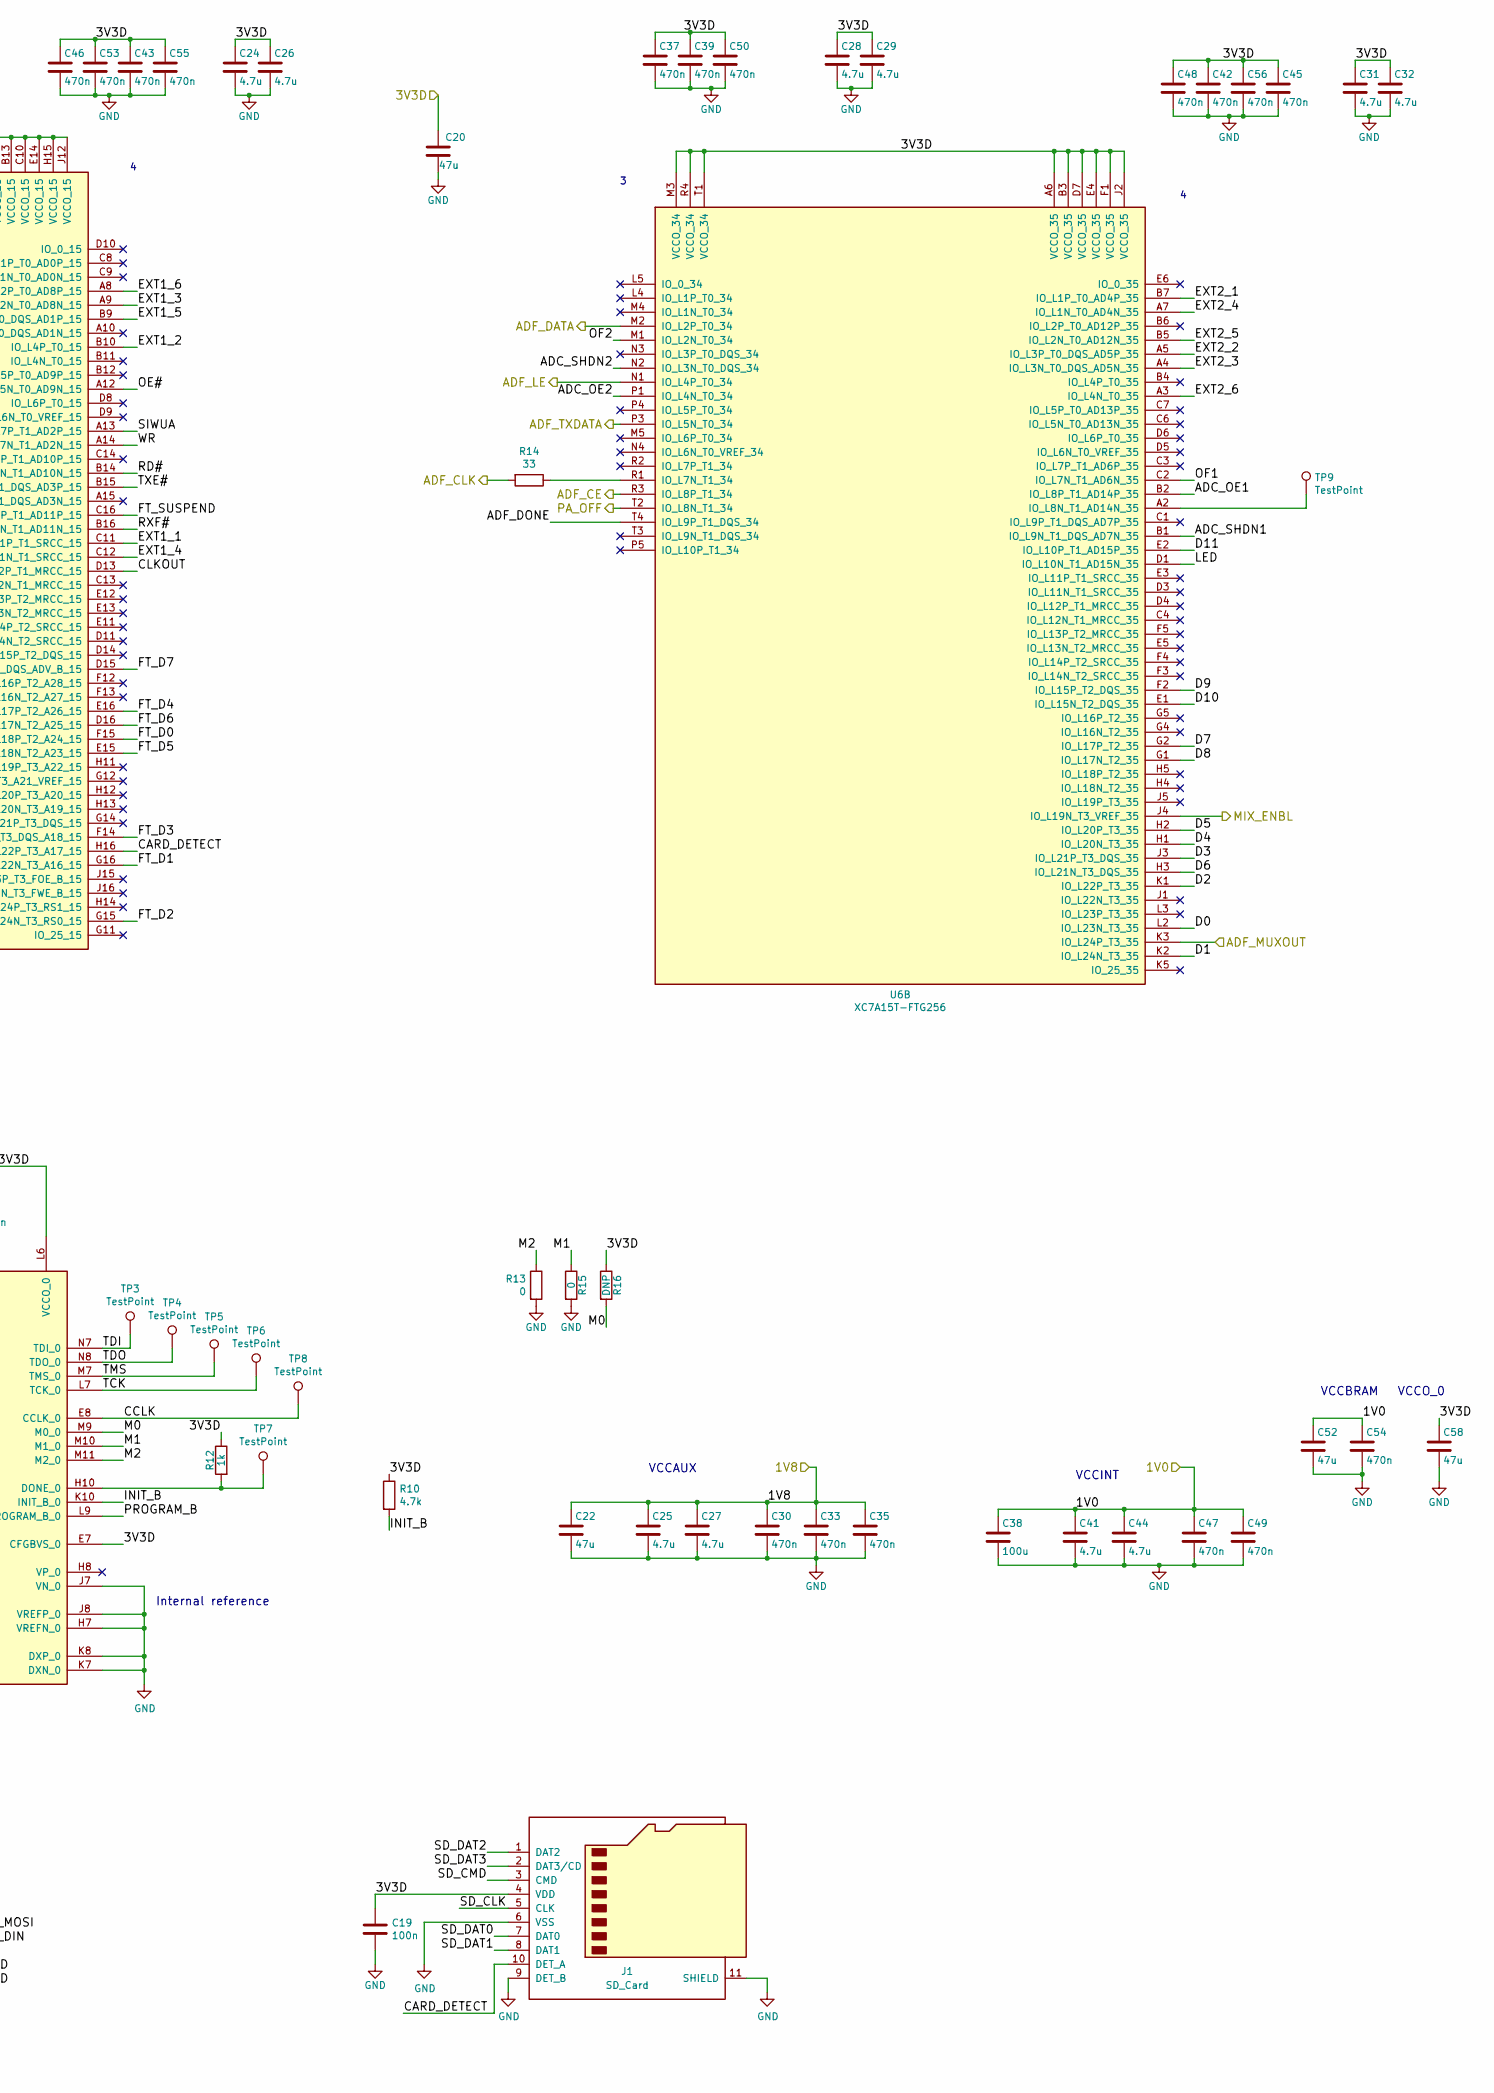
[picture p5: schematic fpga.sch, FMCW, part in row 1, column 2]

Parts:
C14, C16, C30, C33, C34, C35, C36, C37, C39, C40, C42, C43, C45, C46, C47, C48, C49, C50, C51, C53, C54, C55, C56, C57: 470n; C_0603_1608Metric
C17: DNP; C_0402_1005Metric
C18, C19: 100n; C_0402_1005Metric
C20, C22, C52, C58: 47u; C_1206_3216Metric
C21, C23, C24, C25, C26, C27, C28, C29, C31, C32, C41, C44: 4.7u; C_0805_2012Metric
C38: 100u; C_1210_3225Metric
D1: Green; LED_0603_1608Metric
J1: SD_Card; microSD_HC_Hirose_DM3BT-DSF-PEJS
J6: Conn_02x08_Odd_Even; PinHeader_2x07_P2.54mm_Vertical
Q1: DNP(RE1C002UN); SOT-416
R6: 240; R_0402_1005Metric
R7, R16: DNP; R_0402_1005Metric
R8, R13, R15: 0; R_0402_1005Metric
R9, R10, R11: 4.7k; R_0402_1005Metric
R12: 1k; R_0402_1005Metric
R14: 33; R_0402_1005Metric
SW1: SW_PUSH; SW_SPST_PTS810
TP1, TP2, TP3, TP4, TP5, TP6, TP7, TP8, TP9: TestPoint; TestPoint_Loop_D1.80mm_Drill1.0mm_Beaded
U6: XC7A15T-FTG256; Xilinx_FTG256
U7: MX25L3233F; SOP-8_3.9x4.9mm_P1.27mm

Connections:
/1V0: C38.1, C41.1, C44.1, C47.1, C49.1, C52.1, C54.1, U6.E10 (VCCBRAM), U6.F7 (VCCINT), U6.F9 (VCCINT), U6.F11 (VCCBRAM), U6.G6 (VCCINT), U6.H9 (VCCINT), U6.J6 (VCCINT), U6.K9 (VCCINT), U6.L8 (VCCINT); also elsewhere on the board
/1V8: C14.2, C22.1, C25.1, C27.1, C30.1, C33.1, C35.1, U6.G8 (VCCADC_0), U6.G10 (VCCAUX), U6.J10 (VCCAUX), U6.K11 (VCCAUX), U6.L10 (VCCAUX); also elsewhere on the board
/3V3D: C16.1, C18.2, C19.1, C20.1, C21.1, C23.1, C24.1, C26.1, C28.1, C29.1, C31.1, C32.1, C34.1, C36.1, C37.1, C39.1, C40.1, C42.1, C43.1, C45.1, C46.1, C48.1, C50.1, C51.1, C53.1, C55.1, C56.1, C57.2, C58.1, J1.4 (VDD), J6.2, R7.1, R9.1, R10.1, R11.1, R12.1, R16.1, U6.A6 (VCCO_35), U6.A16 (VCCO_15), U6.B3 (VCCO_35), U6.B13 (VCCO_15), U6.C10 (VCCO_15), U6.D7 (VCCO_35), U6.E4 (VCCO_35), U6.E7 (CFGBVS_0), U6.E14 (VCCO_15), U6.F1 (VCCO_35), U6.H15 (VCCO_15), U6.J2 (VCCO_35), U6.J12 (VCCO_15), U6.L6 (VCCO_0), U6.L16 (VCCO_14), U6.M3 (VCCO_34), U6.M13 (VCCO_14), U6.N10 (VCCO_14), U6.P7 (VCCO_14), U6.R4 (VCCO_34), U6.R14 (VCCO_14), U6.T1 (VCCO_34), U6.T11 (VCCO_14), U7.3 (~WP~(SIO2)), U7.7 (~HOLD~(SIO3)), U7.8 (VCC); also elsewhere on the board
/ADF_CE: U6.R3 (IO_L8P_T1_34); also elsewhere on the board
/ADF_CLK: R14.2; also elsewhere on the board
/ADF_DATA: U6.M2 (IO_L2P_T0_34); also elsewhere on the board
/ADF_LE: U6.N1 (IO_L4P_T0_34); also elsewhere on the board
/ADF_MUXOUT: Q1.1 (G), U6.K3 (IO_L24P_T3_35); also elsewhere on the board
/ADF_TXDATA: U6.P3 (IO_L5N_T0_34); also elsewhere on the board
/FPGA_REF: U6.N11 (IO_L13P_T2_MRCC_14); also elsewhere on the board
/MIX_ENBL: U6.J4 (IO_L19N_T3_VREF_35); also elsewhere on the board
/PA_OFF: U6.T2 (IO_L8N_T1_34); also elsewhere on the board
/fpga/ADC_OE1: U6.B2 (IO_L8P_T1_AD14P_35); also elsewhere on the board
/fpga/ADC_OE2: U6.P1 (IO_L4N_T0_34); also elsewhere on the board
/fpga/ADC_SHDN1: U6.B1 (IO_L9N_T1_DQS_AD7N_35); also elsewhere on the board
/fpga/ADC_SHDN2: U6.N2 (IO_L3N_T0_DQS_34); also elsewhere on the board
/fpga/ADF_DONE: C17.1, Q1.3 (D), U6.T4 (IO_L9P_T1_DQS_34)
/fpga/CARD_DETECT: J1.10 (DET_A), U6.H16 (IO_L22P_T3_A17_15)
/fpga/CCLK: TP8.1, U6.E8 (CCLK_0), U7.6 (SCLK)
/fpga/CLKOUT: U6.D13 (IO_L12P_T1_MRCC_15); also elsewhere on the board
/fpga/D0: U6.L2 (IO_L23N_T3_35); also elsewhere on the board
/fpga/D1: U6.K2 (IO_L24N_T3_35); also elsewhere on the board
/fpga/D2: U6.K1 (IO_L22P_T3_35); also elsewhere on the board
/fpga/D3: U6.J3 (IO_L21P_T3_DQS_35); also elsewhere on the board
/fpga/D4: U6.H1 (IO_L20N_T3_35); also elsewhere on the board
/fpga/D5: U6.H2 (IO_L20P_T3_35); also elsewhere on the board
/fpga/D6: U6.H3 (IO_L21N_T3_DQS_35); also elsewhere on the board
/fpga/D7: U6.G2 (IO_L17P_T2_35); also elsewhere on the board
/fpga/D8: U6.G1 (IO_L17N_T2_35); also elsewhere on the board
/fpga/D9: U6.F2 (IO_L15P_T2_DQS_35); also elsewhere on the board
/fpga/D10: U6.E1 (IO_L15N_T2_DQS_35); also elsewhere on the board
/fpga/D11: U6.E2 (IO_L10P_T1_AD15P_35); also elsewhere on the board
/fpga/EXT1_1: J6.3, U6.C11 (IO_L11P_T1_SRCC_15)
/fpga/EXT1_2: J6.5, U6.B10 (IO_L4P_T0_15)
/fpga/EXT1_3: J6.7, U6.A9 (IO_L2N_T0_AD8N_15)
/fpga/EXT1_4: J6.4, U6.C12 (IO_L11N_T1_SRCC_15)
/fpga/EXT1_5: J6.6, U6.B9 (IO_L3P_T0_DQS_AD1P_15)
/fpga/EXT1_6: J6.8, U6.A8 (IO_L2P_T0_AD8P_15)
/fpga/EXT2_1: J6.9, U6.B7 (IO_L1P_T0_AD4P_35)
/fpga/EXT2_2: J6.11, U6.A5 (IO_L3P_T0_DQS_AD5P_35)
/fpga/EXT2_3: J6.13, U6.A4 (IO_L3N_T0_DQS_AD5N_35)
/fpga/EXT2_4: J6.10, U6.A7 (IO_L1N_T0_AD4N_35)
/fpga/EXT2_5: J6.12, U6.B5 (IO_L2N_T0_AD12N_35)
/fpga/EXT2_6: J6.14, U6.A3 (IO_L4N_T0_35)
/fpga/FT_D0: U6.F15 (IO_L18P_T2_A24_15); also elsewhere on the board
/fpga/FT_D1: U6.G16 (IO_L22N_T3_A16_15); also elsewhere on the board
/fpga/FT_D2: U6.G15 (IO_L24N_T3_RS0_15); also elsewhere on the board
/fpga/FT_D3: U6.F14 (IO_L21N_T3_DQS_A18_15); also elsewhere on the board
/fpga/FT_D4: U6.E16 (IO_L17P_T2_A26_15); also elsewhere on the board
/fpga/FT_D5: U6.E15 (IO_L18N_T2_A23_15); also elsewhere on the board
/fpga/FT_D6: U6.D16 (IO_L17N_T2_A25_15); also elsewhere on the board
/fpga/FT_D7: U6.D15 (IO_L15N_T2_DQS_ADV_B_15); also elsewhere on the board
/fpga/FT_SUSPEND: U6.C16 (IO_L10P_T1_AD11P_15); also elsewhere on the board
/fpga/INIT_B: R10.2, U6.K10 (INIT_B_0)
/fpga/LED: R6.1, U6.D1 (IO_L10N_T1_AD15N_35)
/fpga/M0: R16.2, U6.M9 (M0_0)
/fpga/M1: R15.1, U6.M10 (M1_0)
/fpga/M2: R13.1, U6.M11 (M2_0)
/fpga/OE#: U6.A12 (IO_L5N_T0_AD9N_15); also elsewhere on the board
/fpga/OF1: U6.C2 (IO_L7N_T1_AD6N_35); also elsewhere on the board
/fpga/OF2: U6.M1 (IO_L2N_T0_34); also elsewhere on the board
/fpga/PROGRAM_B: R9.2, SW1.1, U6.L9 (PROGRAM_B_0)
/fpga/RD#: U6.B14 (IO_L8N_T1_AD10N_15); also elsewhere on the board
/fpga/RXF#: U6.B16 (IO_L10N_T1_AD11N_15); also elsewhere on the board
/fpga/SD_CLK: J1.5 (CLK), U6.N14 (IO_L12P_T1_MRCC_14)
/fpga/SD_CMD: J1.3 (CMD), U6.P16 (IO_L8N_T1_D12_14)
/fpga/SD_DAT0: J1.7 (DAT0), U6.N16 (IO_L7N_T1_D10_14)
/fpga/SD_DAT1: J1.8 (DAT1), U6.M16 (IO_L7P_T1_D09_14)
/fpga/SD_DAT2: J1.1 (DAT2), U6.R16 (IO_L9N_T1_DQS_D13_14)
/fpga/SD_DAT3: J1.2 (DAT3/CD), U6.R15 (IO_L9P_T1_DQS_14)
/fpga/SIWUA: U6.A13 (IO_L7P_T1_AD2P_15); also elsewhere on the board
/fpga/SPI_CS: R11.2, U6.L12 (IO_L6P_T0_FCS_B_14), U7.1 (~CS)
/fpga/SPI_DIN: TP1.1, U6.J14 (IO_L1N_T0_D01_DIN_14), U7.2 (SO(SIO1))
/fpga/SPI_MOSI: TP2.1, U6.J13 (IO_L1P_T0_D00_MOSI_14), U7.5 (SI(SIO0))
/fpga/TCK: TP6.1, U6.L7 (TCK_0); also elsewhere on the board
/fpga/TDI: TP3.1, U6.N7 (TDI_0); also elsewhere on the board
/fpga/TDO: TP4.1, U6.N8 (TDO_0); also elsewhere on the board
/fpga/TMS: TP5.1, U6.M7 (TMS_0); also elsewhere on the board
/fpga/TXE#: U6.B15 (IO_L9P_T1_DQS_AD3P_15); also elsewhere on the board
/fpga/WR: U6.A14 (IO_L7N_T1_AD2N_15); also elsewhere on the board
GND: C14.1, C16.2, C17.2, C18.1, C19.2, C20.2, C21.2, C22.2, C23.2, C24.2, C25.2, C26.2, C27.2, C28.2, C29.2, C30.2, C31.2, C32.2, C33.2, C34.2, C35.2, C36.2, C37.2, C38.2, C39.2, C40.2, C41.2, C42.2, C43.2, C44.2, C45.2, C46.2, C47.2, C48.2, C49.2, C50.2, C51.2, C52.2, C53.2, C54.2, C55.2, C56.2, C57.1, C58.2, D1.1 (K), J1.6 (VSS), J1.9 (DET_B), J1.11 (SHIELD), J6.1, Q1.2 (S), R8.2, R13.2, R15.2, SW1.2, U6.A1 (GND), U6.A11 (GND), U6.B8 (GND), U6.C5 (GND), U6.C15 (GND), U6.D2 (GND), U6.D12 (GND), U6.E9 (GND), U6.F6 (GND), U6.F8 (VCCBATT_0), U6.F10 (GND), U6.F16 (GND), U6.G3 (GND), U6.G7 (GNDADC_0), U6.G9 (GND), U6.G13 (GND), U6.H6 (GND), U6.H7 (VREFN_0), U6.J7 (VN_0), U6.J8 (VREFP_0), U6.J9 (GND), U6.J11 (GND), U6.K4 (GND), U6.K6 (GND), U6.K7 (DXN_0), U6.K8 (DXP_0), U6.K14 (GND), U6.L1 (GND), U6.L11 (GND), U6.M8 (GND), U6.N5 (GND), U6.N15 (GND), U6.P2 (GND), U6.P12 (GND), U6.R9 (GND), U6.T6 (GND), U6.T16 (GND), U7.4 (GND); also elsewhere on the board
unnamed: D1.2 (A), R6.2
unnamed: R7.2, R8.1, U6.L15 (IO_L3P_T0_DQS_PUDC_B_14)
unnamed: R12.2, TP7.1, U6.H10 (DONE_0)
unnamed: R14.1, U6.R1 (IO_L7N_T1_34)
unnamed: TP9.1, U6.A2 (IO_L8N_T1_AD14N_35)

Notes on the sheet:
62 (22) mA
Power supply ramp time: 0.2 ms - 50 ms
TODO: Programming pins
Mode M[2:0] Master serial 000 Master SPI 001 Master BPI 010 Master SelectMap 100 JTAG 101 Slave SelectMap 110 Slave serial 111
62 (2) mA
220 mA
3V6: 95 (78) mA 3V3: 3 mA
215 (95) mA
201 (1) mA
20 (0) mA
Internal reference
VCCAUX
VCCINT
VCCBRAM
VCCO_0

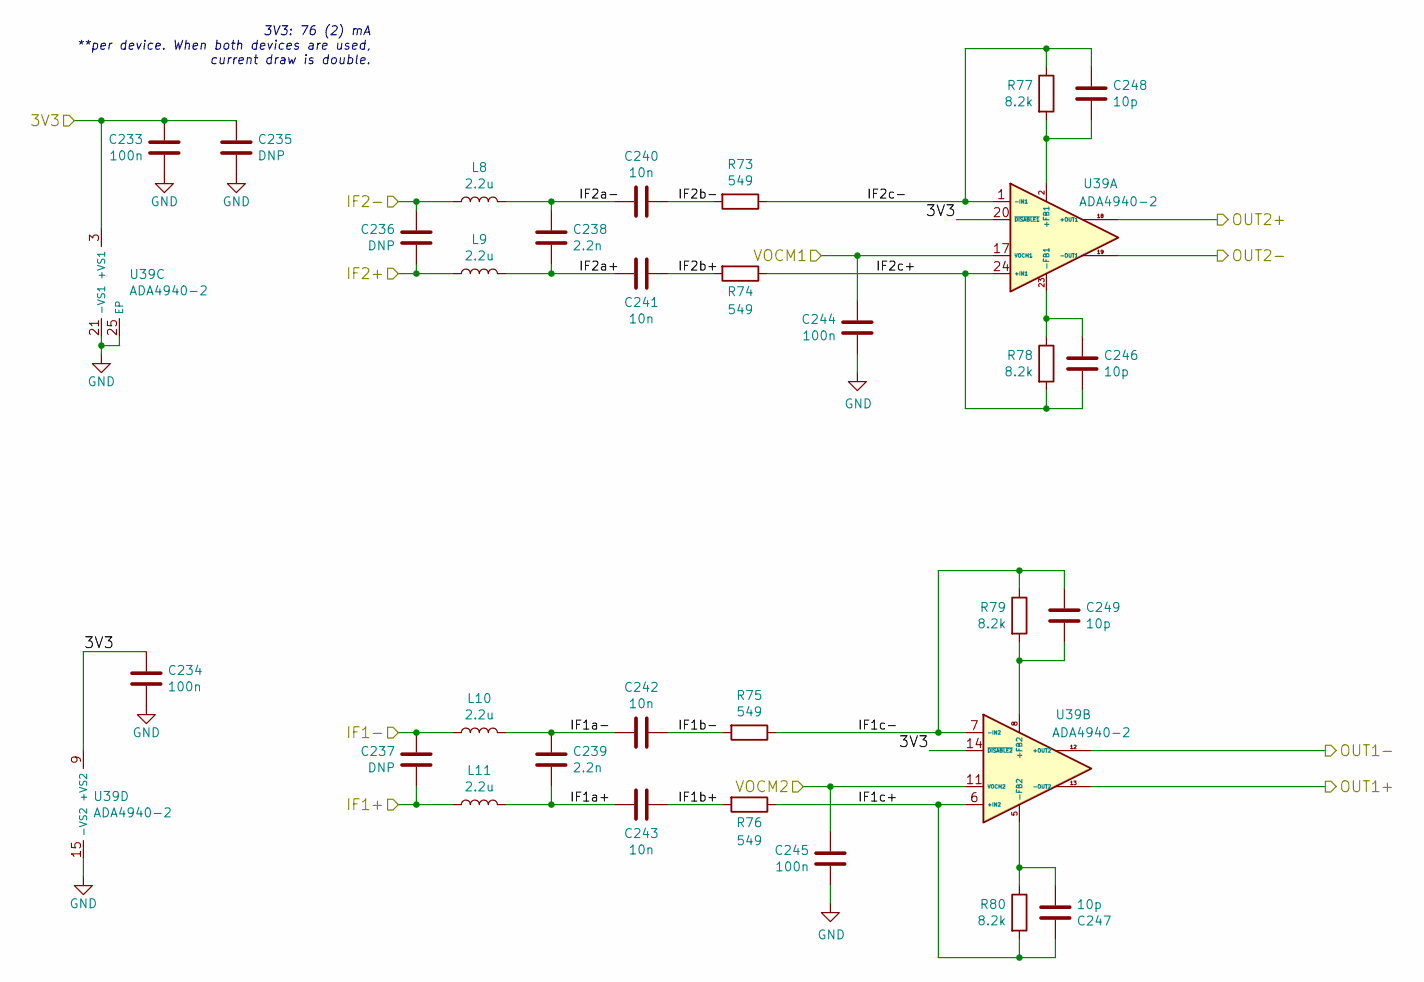
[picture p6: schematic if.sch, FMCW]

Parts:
C233, C234, C244, C245: 100n; C_0402_1005Metric
C235: DNP; C_0805_2012Metric
C236, C237: DNP; C_0402_1005Metric
C238, C239: 2.2n; C_0402_1005Metric
C240, C241, C242, C243: 10n; C_0402_1005Metric
C246, C247, C248, C249: 10p; C_0402_1005Metric
L8, L9, L10, L11: 2.2u; L_0603_1608Metric
R73, R74, R75, R76: 549; R_0402_1005Metric
R77, R78, R79, R80: 8.2k; R_0402_1005Metric
U39: ADA4940-2; LFCSP-24-1EP_4x4mm_P0.5mm_EP2.5x2.5mm_ThermalVias

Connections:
/3V3A: C233.1, C234.1, C235.1, U39.3 (+VS1), U39.4 (+VS1), U39.9 (+VS2), U39.10 (+VS2), U39.14 (~DISABLE2), U39.20 (~DISABLE1); also elsewhere on the board
/ADC1+: U39.13 (-OUT2); also elsewhere on the board
/ADC1-: U39.12 (+OUT2); also elsewhere on the board
/ADC2+: U39.18 (+OUT1); also elsewhere on the board
/ADC2-: U39.19 (-OUT1); also elsewhere on the board
/ADC_VCM1: C244.1, U39.17 (VOCM1); also elsewhere on the board
/ADC_VCM2: C245.1, U39.11 (VOCM2); also elsewhere on the board
/if/IF1+: C237.2, L11.1; also elsewhere on the board
/if/IF1-: C237.1, L10.1; also elsewhere on the board
/if/IF1a+: C239.2, C243.2, L11.2
/if/IF1a-: C239.1, C242.2, L10.2
/if/IF1b+: C243.1, R76.2
/if/IF1b-: C242.1, R75.2
/if/IF1c+: C247.1, R76.1, R80.2, U39.6 (+IN2)
/if/IF1c-: C249.1, R75.1, R79.1, U39.7 (-IN2)
/if/IF2+: C236.2, L9.1; also elsewhere on the board
/if/IF2-: C236.1, L8.1; also elsewhere on the board
/if/IF2a+: C238.2, C241.2, L9.2
/if/IF2a-: C238.1, C240.2, L8.2
/if/IF2b+: C241.1, R74.2
/if/IF2b-: C240.1, R73.2
/if/IF2c+: C246.2, R74.1, R78.2, U39.24 (+IN1)
/if/IF2c-: C248.1, R73.1, R77.1, U39.1 (-IN1)
GND: C233.2, C234.2, C235.2, C244.2, C245.2, U39.15 (-VS2), U39.16 (-VS2), U39.21 (-VS1), U39.22 (-VS1), U39.25 (EP); also elsewhere on the board
unnamed: C246.1, R78.1, U39.23 (-FB1)
unnamed: C247.2, R80.1, U39.5 (-FB2)
unnamed: C248.2, R77.2, U39.2 (+FB1)
unnamed: C249.2, R79.2, U39.8 (+FB2)

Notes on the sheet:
3V3: 76 (2) mA **per device. When both devices are used, current draw is double.

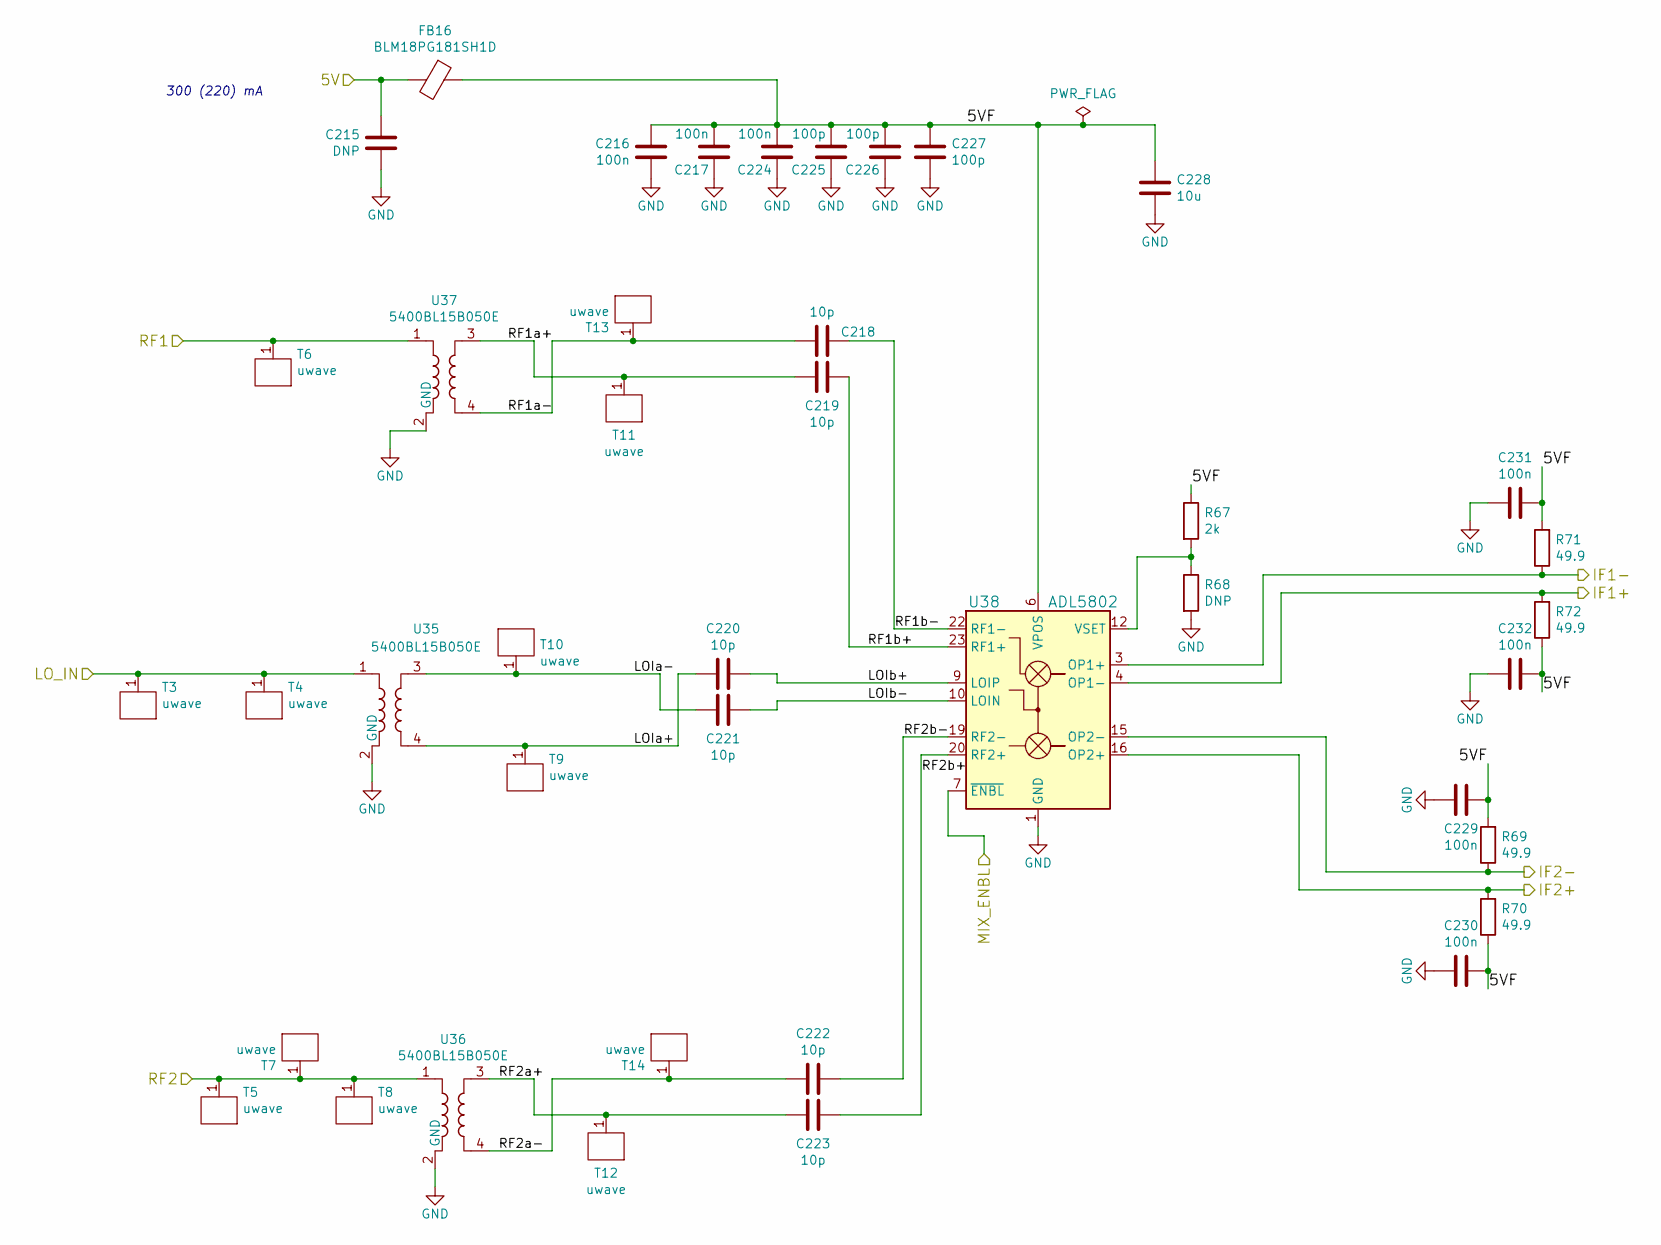
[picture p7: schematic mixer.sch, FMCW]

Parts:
C215: DNP; C_0805_2012Metric
C216, C217, C224, C229, C230, C231, C232: 100n; C_0402_1005Metric
C218, C219, C220, C221, C222, C223: 10p; RF_C_0201_0603Metric
C225, C226, C227: 100p; C_0402_1005Metric
C228: 10u; C_0805_2012Metric
FB16: BLM18PG181SH1D; L_0603_1608Metric
R67: 2k; R_0402_1005Metric
R68: DNP; R_0402_1005Metric
R69, R70, R71, R72: 49.9; R_0402_1005Metric
T3, T4, T5, T6, T7, T8: uwave; uwm_0.38_0.17_90
T9, T13, T14: uwave; balun_exit
T10, T11, T12: uwave; balun_exit_inv
U35, U36, U37: 5400BL15B050E; Balun_Johanson_5400BL15B050E
U38: ADL5802; LFCSP-24-1EP_4x4mm_P0.5mm_EP2.5x2.5mm_ThermalVias

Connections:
/5VMIX: C215.2, FB16.2; also elsewhere on the board
/LO: T3.1, T4.1, U35.1; also elsewhere on the board
/MIX_ENBL: U38.7 (~ENBL); also elsewhere on the board
/RF1: T6.1, U37.1; also elsewhere on the board
/RF2: T5.1, T7.1, T8.1, U36.1; also elsewhere on the board
/if/IF1+: R72.2, U38.4 (OP1-); also elsewhere on the board
/if/IF1-: R71.1, U38.3 (OP1+); also elsewhere on the board
/if/IF2+: R70.2, U38.16 (OP2+); also elsewhere on the board
/if/IF2-: R69.1, U38.15 (OP2-); also elsewhere on the board
/mixer/5VF: C216.2, C217.2, C224.2, C225.2, C226.2, C227.2, C228.2, C229.2, C230.2, C231.2, C232.2, FB16.1, R67.1, R69.2, R70.1, R71.2, R72.1, U38.6 (VPOS), U38.13 (VPOS), U38.24 (VPOS)
/mixer/LOIa+: C220.2, T9.1, U35.4
/mixer/LOIa-: C221.2, T10.1, U35.3
/mixer/LOIb+: C220.1, U38.9 (LOIP)
/mixer/LOIb-: C221.1, U38.10 (LOIN)
/mixer/RF1a+: C219.2, T11.1, U37.3
/mixer/RF1a-: C218.2, T13.1, U37.4
/mixer/RF1b+: C219.1, U38.23 (RF1+)
/mixer/RF1b-: C218.1, U38.22 (RF1-)
/mixer/RF2a+: C223.2, T12.1, U36.3
/mixer/RF2a-: C222.2, T14.1, U36.4
/mixer/RF2b+: C223.1, U38.20 (RF2+)
/mixer/RF2b-: C222.1, U38.19 (RF2-)
GND: C215.1, C216.1, C217.1, C224.1, C225.1, C226.1, C227.1, C228.1, C229.1, C230.1, C231.1, C232.1, R68.2, U35.2 (GND), U35.5 (GND), U36.2 (GND), U36.5 (GND), U37.2 (GND), U37.5 (GND), U38.1 (GND), U38.2 (GND), U38.5 (GND), U38.8 (GND), U38.11 (GND), U38.14 (GND), U38.17 (GND), U38.18 (GND), U38.21 (GND), U38.25 (GND); also elsewhere on the board
unnamed: R67.2, R68.1, U38.12 (VSET)

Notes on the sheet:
300 (220) mA

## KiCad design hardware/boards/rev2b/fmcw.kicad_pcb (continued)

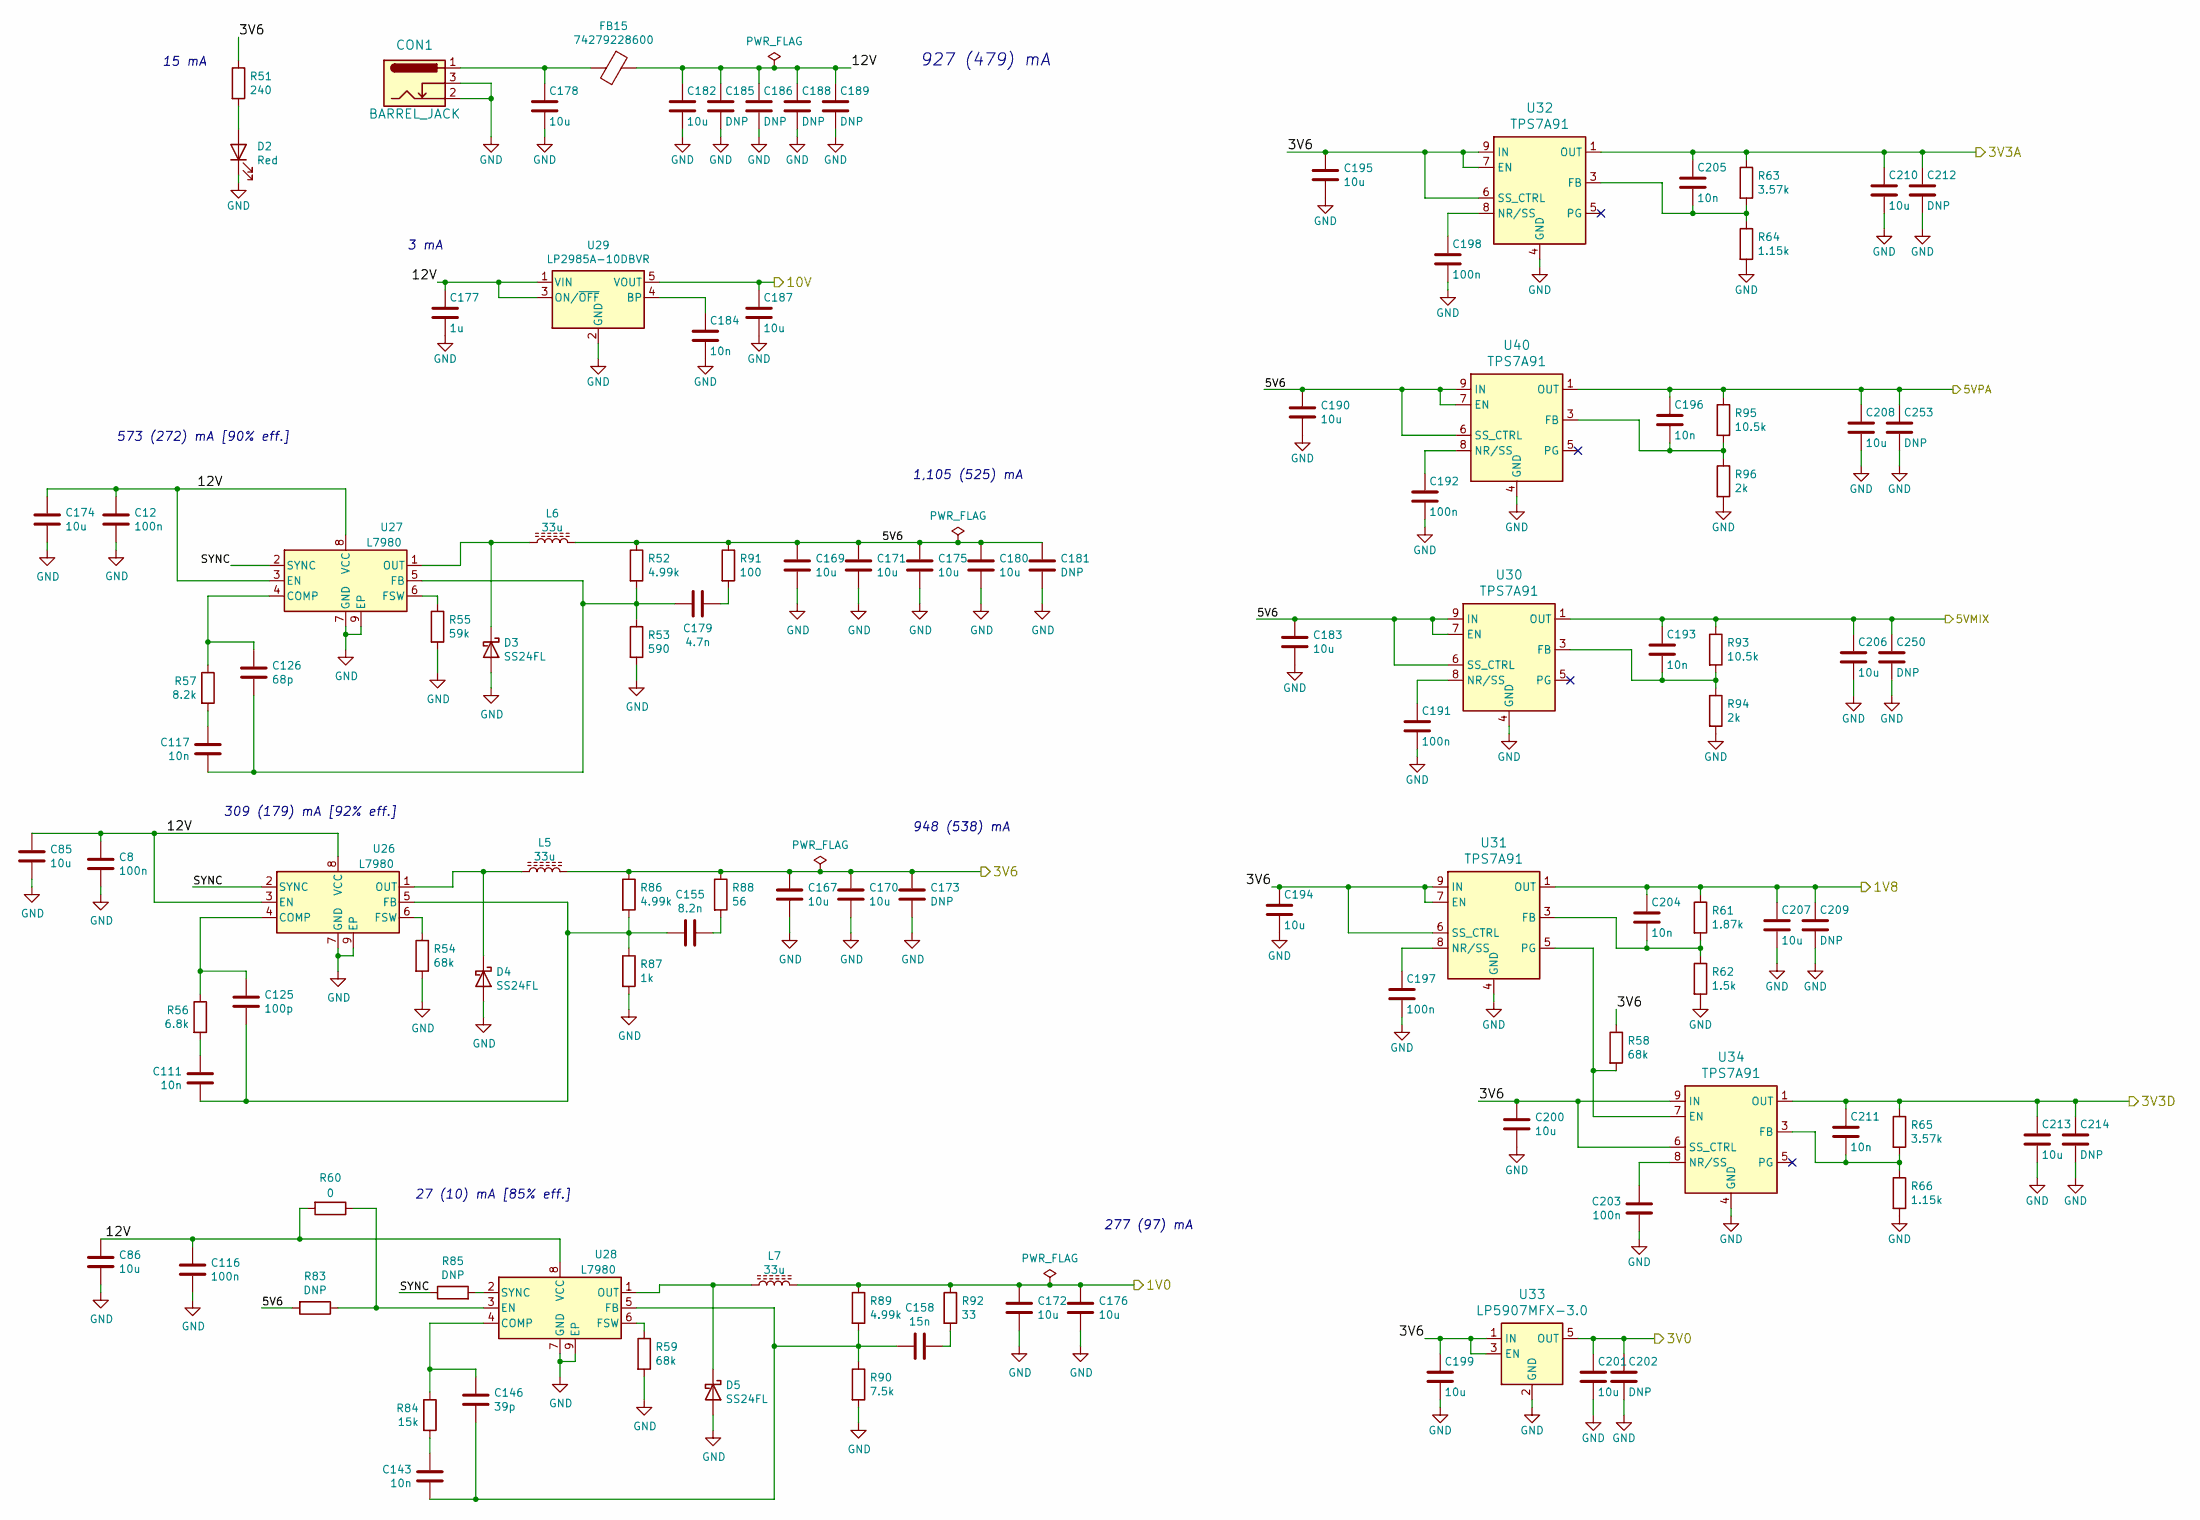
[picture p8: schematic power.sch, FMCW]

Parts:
C8, C12, C116, C191, C192, C197, C198, C203: 100n; C_0402_1005Metric
C85, C86, C167, C169, C170, C171, C172, C174, C175, C176, C178, C180, C182, C183, C187, C190, C194, C195, C199, C200, C201, C206, C207, C208, C210, C213: 10u; C_0805_2012Metric
C111, C117, C143, C184, C193, C196, C204, C205, C211: 10n; C_0402_1005Metric
C125: 100p; C_0402_1005Metric
C126: 68p; C_0402_1005Metric
C146: 39p; C_0402_1005Metric
C155: 8.2n; C_0402_1005Metric
C158: 15n; C_0402_1005Metric
C173, C181, C185, C186, C188, C189, C202, C209, C212, C214, C250, C253: DNP; C_0805_2012Metric
C177: 1u; C_0603_1608Metric
C179: 4.7n; C_0402_1005Metric
CON1: BARREL_JACK; BarrelJack_Wuerth_6941xx301002
D2: Red; LED_0603_1608Metric
D3, D4, D5: SS24FL; D_SOD-123F
FB15: 74279228600; L_0603_1608Metric
L5, L6: 33u; L_Wuerth_HCI-1365
L7: 33u; L_Bourns_SRR6040A
R51: 240; R_0402_1005Metric
R52, R86, R89: 4.99k; R_0402_1005Metric
R53: 590; R_0402_1005Metric
R54, R58, R59: 68k; R_0402_1005Metric
R55: 59k; R_0402_1005Metric
R56: 6.8k; R_0402_1005Metric
R57: 8.2k; R_0402_1005Metric
R60: 0; R_0402_1005Metric
R61: 1.87k; R_0402_1005Metric
R62: 1.5k; R_0402_1005Metric
R63, R65: 3.57k; R_0402_1005Metric
R64, R66: 1.15k; R_0402_1005Metric
R83, R85: DNP; R_0402_1005Metric
R84: 15k; R_0402_1005Metric
R87: 1k; R_0402_1005Metric
R88: 56; R_0402_1005Metric
R90: 7.5k; R_0402_1005Metric
R91: 100; R_0402_1005Metric
R92: 33; R_0402_1005Metric
R93, R95: 10.5k; R_0402_1005Metric
R94, R96: 2k; R_0402_1005Metric
U26, U27, U28: L7980; HSOP-8-1EP_3.9x4.9mm_P1.27mm_EP2.3x2.3mm_ThermalVias
U29: LP2985A-10DBVR; SOT-23-5
U30, U31, U32, U34, U40: TPS7A91; Texas_S-PDSO-N10_EP1.2x2mm_ThermalVias
U33: LP5907MFX-3.0; SOT-23-5

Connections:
/1V0: C172.1, C176.1, L7.2, R89.1, R92.1; also elsewhere on the board
/1V8: C204.1, C207.1, C209.1, R61.1, U31.1 (OUT), U31.2 (OUT); also elsewhere on the board
/3V0: C201.1, C202.1, U33.5 (OUT); also elsewhere on the board
/3V3A: C205.1, C210.1, C212.1, R63.1, U32.1 (OUT), U32.2 (OUT); also elsewhere on the board
/3V3D: C211.1, C213.1, C214.1, R65.1, U34.1 (OUT), U34.2 (OUT); also elsewhere on the board
/3V6: C167.1, C170.1, C173.1, C194.1, C195.1, C199.1, C200.1, L5.2, R51.1, R58.1, R86.1, R88.1, U31.6 (SS_CTRL), U31.7 (EN), U31.9 (IN), U31.10 (IN), U32.6 (SS_CTRL), U32.7 (EN), U32.9 (IN), U32.10 (IN), U33.1 (IN), U33.3 (EN), U34.6 (SS_CTRL), U34.9 (IN), U34.10 (IN); also elsewhere on the board
/5VMIX: C193.1, C206.1, C250.1, R93.1, U30.1 (OUT), U30.2 (OUT); also elsewhere on the board
/5VPA: C196.1, C208.1, C253.1, R95.1, U40.1 (OUT), U40.2 (OUT); also elsewhere on the board
/10V: C187.1, U29.5 (VOUT); also elsewhere on the board
/power/5V6: C169.1, C171.1, C175.1, C180.1, C181.1, C183.1, C190.1, L6.2, R52.1, R83.2, R91.1, U30.6 (SS_CTRL), U30.7 (EN), U30.9 (IN), U30.10 (IN), U40.6 (SS_CTRL), U40.7 (EN), U40.9 (IN), U40.10 (IN)
/power/12V: C8.1, C12.1, C85.1, C86.1, C116.1, C174.1, C177.1, C182.1, C185.1, C186.1, C188.1, C189.1, FB15.1, R60.2, U26.3 (EN), U26.8 (VCC), U27.3 (EN), U27.8 (VCC), U28.8 (VCC), U29.1 (VIN), U29.3 (ON/~OFF~)
/power/SYNC: R85.1, U26.2 (SYNC), U27.2 (SYNC)
GND: C8.2, C12.2, C85.2, C86.2, C116.2, C167.2, C169.2, C170.2, C171.2, C172.2, C173.2, C174.2, C175.2, C176.2, C177.2, C178.2, C180.2, C181.2, C182.2, C183.2, C184.2, C185.2, C186.2, C187.2, C188.2, C189.2, C190.2, C191.2, C192.2, C194.2, C195.2, C197.2, C198.2, C199.2, C200.2, C201.2, C202.2, C203.2, C206.2, C207.2, C208.2, C209.2, C210.2, C212.2, C213.2, C214.2, C250.2, C253.2, CON1.2, CON1.3, D2.1 (K), D3.2 (A), D4.2 (A), D5.2 (A), R53.2, R54.2, R55.2, R59.2, R62.2, R64.2, R66.2, R87.2, R90.2, R94.2, R96.2, U26.7 (GND), U26.9 (EP), U27.7 (GND), U27.9 (EP), U28.7 (GND), U28.9 (EP), U29.2 (GND), U30.4 (GND), U30.11 (GND), U31.4 (GND), U31.11 (GND), U32.4 (GND), U32.11 (GND), U33.2 (GND), U34.4 (GND), U34.11 (GND), U40.4 (GND), U40.11 (GND); also elsewhere on the board
unnamed: C111.1, R56.2
unnamed: C111.2, C125.2, C155.2, R86.2, R87.1, U26.5 (FB)
unnamed: C117.1, R57.2
unnamed: C117.2, C126.2, C179.2, R52.2, R53.1, U27.5 (FB)
unnamed: C125.1, R56.1, U26.4 (COMP)
unnamed: C126.1, R57.1, U27.4 (COMP)
unnamed: C143.1, R84.2
unnamed: C143.2, C146.2, C158.2, R89.2, R90.1, U28.5 (FB)
unnamed: C146.1, R84.1, U28.4 (COMP)
unnamed: C155.1, R88.2
unnamed: C158.1, R92.2
unnamed: C178.1, CON1.1, FB15.2
unnamed: C179.1, R91.2
unnamed: C184.1, U29.4 (BP)
unnamed: C191.1, U30.8 (NR/SS)
unnamed: C192.1, U40.8 (NR/SS)
unnamed: C193.2, R93.2, R94.1, U30.3 (FB)
unnamed: C196.2, R95.2, R96.1, U40.3 (FB)
unnamed: C197.1, U31.8 (NR/SS)
unnamed: C198.1, U32.8 (NR/SS)
unnamed: C203.1, U34.8 (NR/SS)
unnamed: C204.2, R61.2, R62.1, U31.3 (FB)
unnamed: C205.2, R63.2, R64.1, U32.3 (FB)
unnamed: C211.2, R65.2, R66.1, U34.3 (FB)
unnamed: D2.2 (A), R51.2
unnamed: D3.1 (K), L6.1, U27.1 (OUT)
unnamed: D4.1 (K), L5.1, U26.1 (OUT)
unnamed: D5.1 (K), L7.1, U28.1 (OUT)
unnamed: R54.1, U26.6 (FSW)
unnamed: R55.1, U27.6 (FSW)
unnamed: R58.2, U31.5 (PG), U34.7 (EN)
unnamed: R59.1, U28.6 (FSW)
unnamed: R60.1, R83.1, U28.3 (EN)
unnamed: R85.2, U28.2 (SYNC)

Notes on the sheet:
573 (272) mA [90% eff.]
15 mA
309 (179) mA [92% eff.]
3 mA
27 (10) mA [85% eff.]
1,105 (525) mA
948 (538) mA
927 (479) mA
277 (97) mA

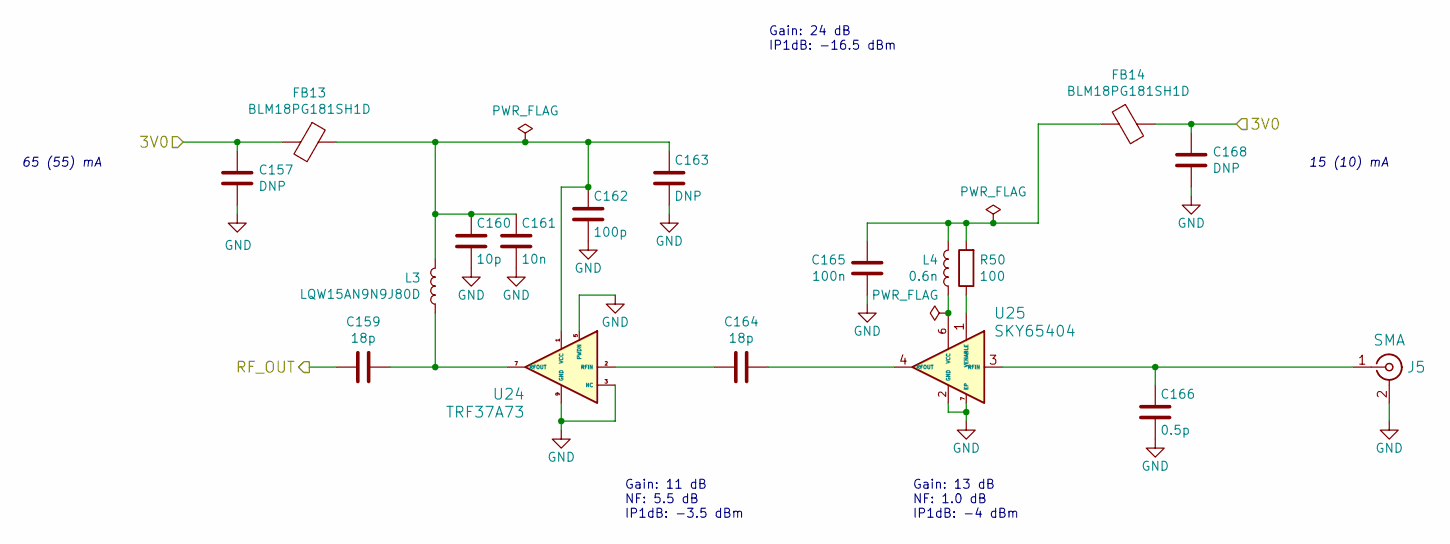
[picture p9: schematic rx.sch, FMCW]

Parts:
C145, C156: DNP; C_0805_2012Metric
C147, C152: 18p; RF_C_0201_0603Metric
C148: 10p; C_0402_1005Metric
C149: 10n; C_0402_1005Metric
C150: 100p; C_0402_1005Metric
C153: 100n; C_0402_1005Metric
C154: 0.5p; RF_C_0201_0603Metric
C163: DNP; C_0603_1608Metric
FB13, FB14: BLM18PG181SH1D; L_0603_1608Metric
J4: SMA; BU-1420701851_SMA
L1: LQW15AN9N9J80D; RF_Bypass_C_0402_1005Metric
L2: 0.6n; L_0402_1005Metric
R49: 100; R_0402_1005Metric
U22: TRF37A73; WSON-8-1EP_2x2mm_P0.5mm_EP0.9x1.6mm_ThermalVias
U23: SKY65404; Skyworks_SKY65404-31

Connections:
/3V0: C145.1, C156.1, FB13.2, FB14.2; also elsewhere on the board
/RF1: C147.2; also elsewhere on the board
GND: C145.2, C148.2, C149.2, C150.2, C153.2, C154.2, C156.2, C163.2, J4.2 (Ext), U22.3 (NC), U22.4 (NC), U22.5 (PWDN), U22.6 (NC), U22.8 (NC), U22.9 (GND), U23.2 (GND), U23.5 (GND), U23.7 (EP); also elsewhere on the board
unnamed: C147.1, L1.1, U22.7 (RFOUT)
unnamed: C152.1, U23.4 (RFOUT)
unnamed: C152.2, U22.2 (RFIN)
unnamed: C154.1, J4.1 (In), U23.3 (RFIN)
unnamed: L2.1, U23.6 (VCC)
unnamed: R49.1, U23.1 (VENABLE)

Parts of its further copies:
C151: DNP; C_0603_1608Metric
C157, C168: DNP; C_0805_2012Metric
C159, C164: 18p; RF_C_0201_0603Metric
C160: 10p; C_0402_1005Metric
C161: 10n; C_0402_1005Metric
C162: 100p; C_0402_1005Metric
C165: 100n; C_0402_1005Metric
C166: 0.5p; RF_C_0201_0603Metric
FB11, FB12: BLM18PG181SH1D; L_0603_1608Metric
J5: SMA; BU-1420701851_SMA
L3: LQW15AN9N9J80D; RF_Bypass_C_0402_1005Metric
L4: 0.6n; L_0402_1005Metric
R50: 100; R_0402_1005Metric
U24: TRF37A73; WSON-8-1EP_2x2mm_P0.5mm_EP0.9x1.6mm_ThermalVias
U25: SKY65404; Skyworks_SKY65404-31

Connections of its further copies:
/3V0: C157.1, C168.1, FB11.2, FB12.2; also elsewhere on the board
/RF2: C159.2; also elsewhere on the board
GND: C151.2, C157.2, C160.2, C161.2, C162.2, C165.2, C166.2, C168.2, J5.2 (Ext), U24.3 (NC), U24.4 (NC), U24.5 (PWDN), U24.6 (NC), U24.8 (NC), U24.9 (GND), U25.2 (GND), U25.5 (GND), U25.7 (EP); also elsewhere on the board
unnamed: C159.1, L3.1, U24.7 (RFOUT)
unnamed: C164.1, U25.4 (RFOUT)
unnamed: C164.2, U24.2 (RFIN)
unnamed: C166.1, J5.1 (In), U25.3 (RFIN)
unnamed: L4.1, U25.6 (VCC)
unnamed: R50.1, U25.1 (VENABLE)

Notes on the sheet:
65 (55) mA
Gain: 11 dB NF: 5.5 dB IP1dB: -3.5 dBm
Gain: 24 dB IP1dB: -16.5 dBm
Gain: 13 dB NF: 1.0 dB IP1dB: -4 dBm
15 (10) mA

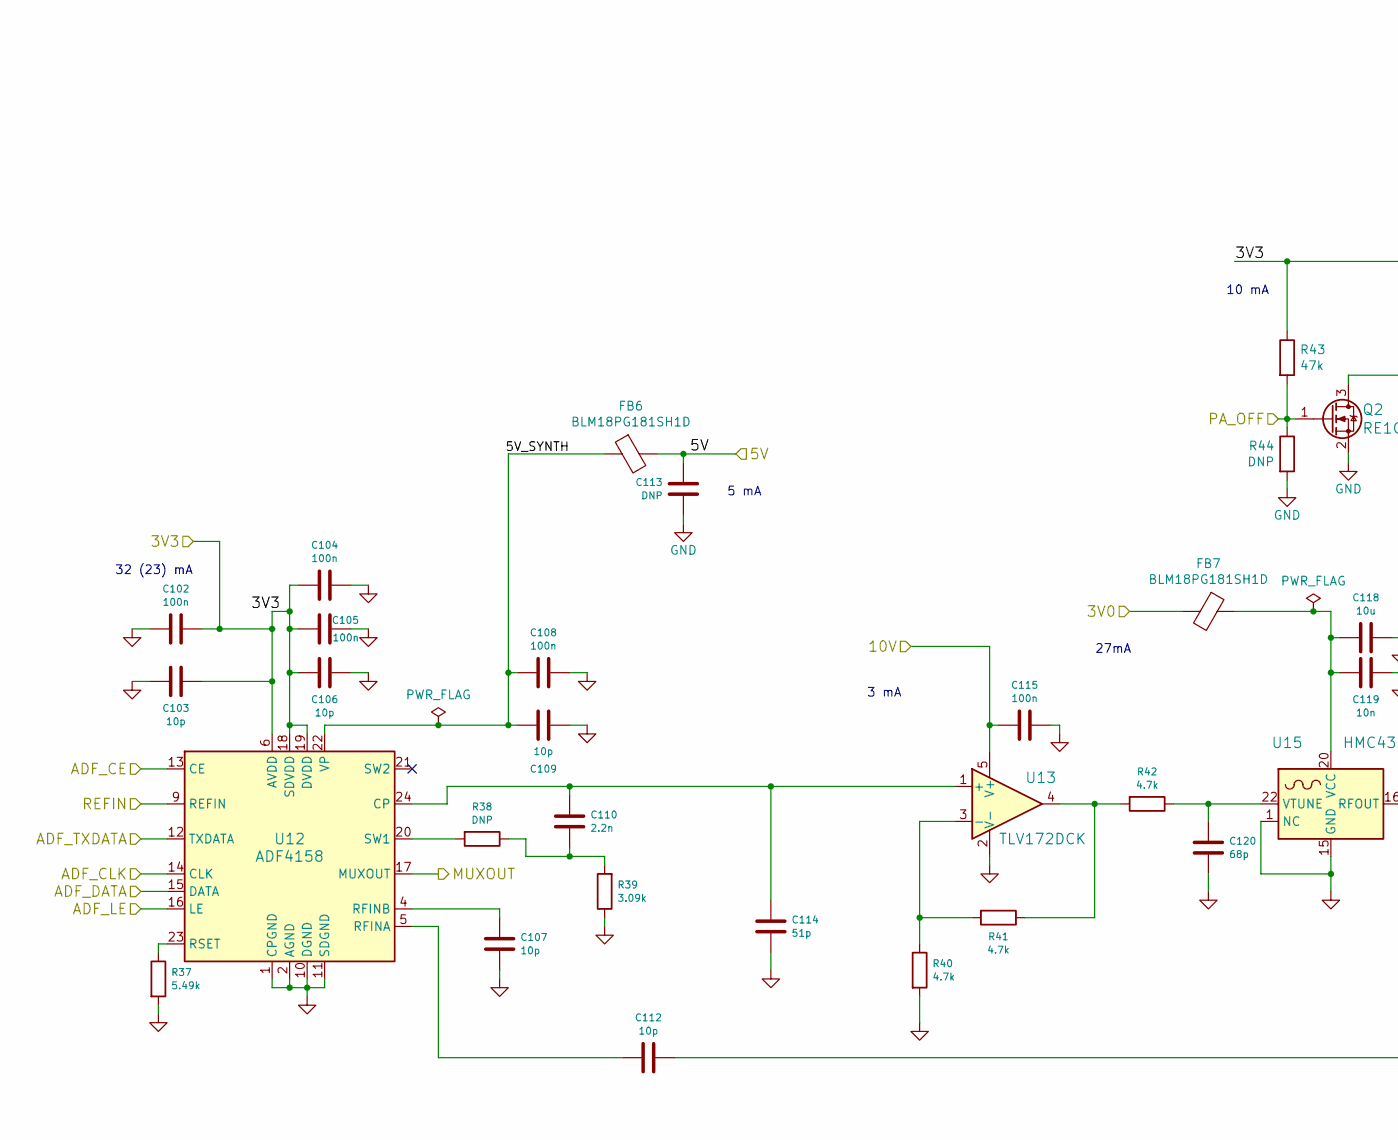
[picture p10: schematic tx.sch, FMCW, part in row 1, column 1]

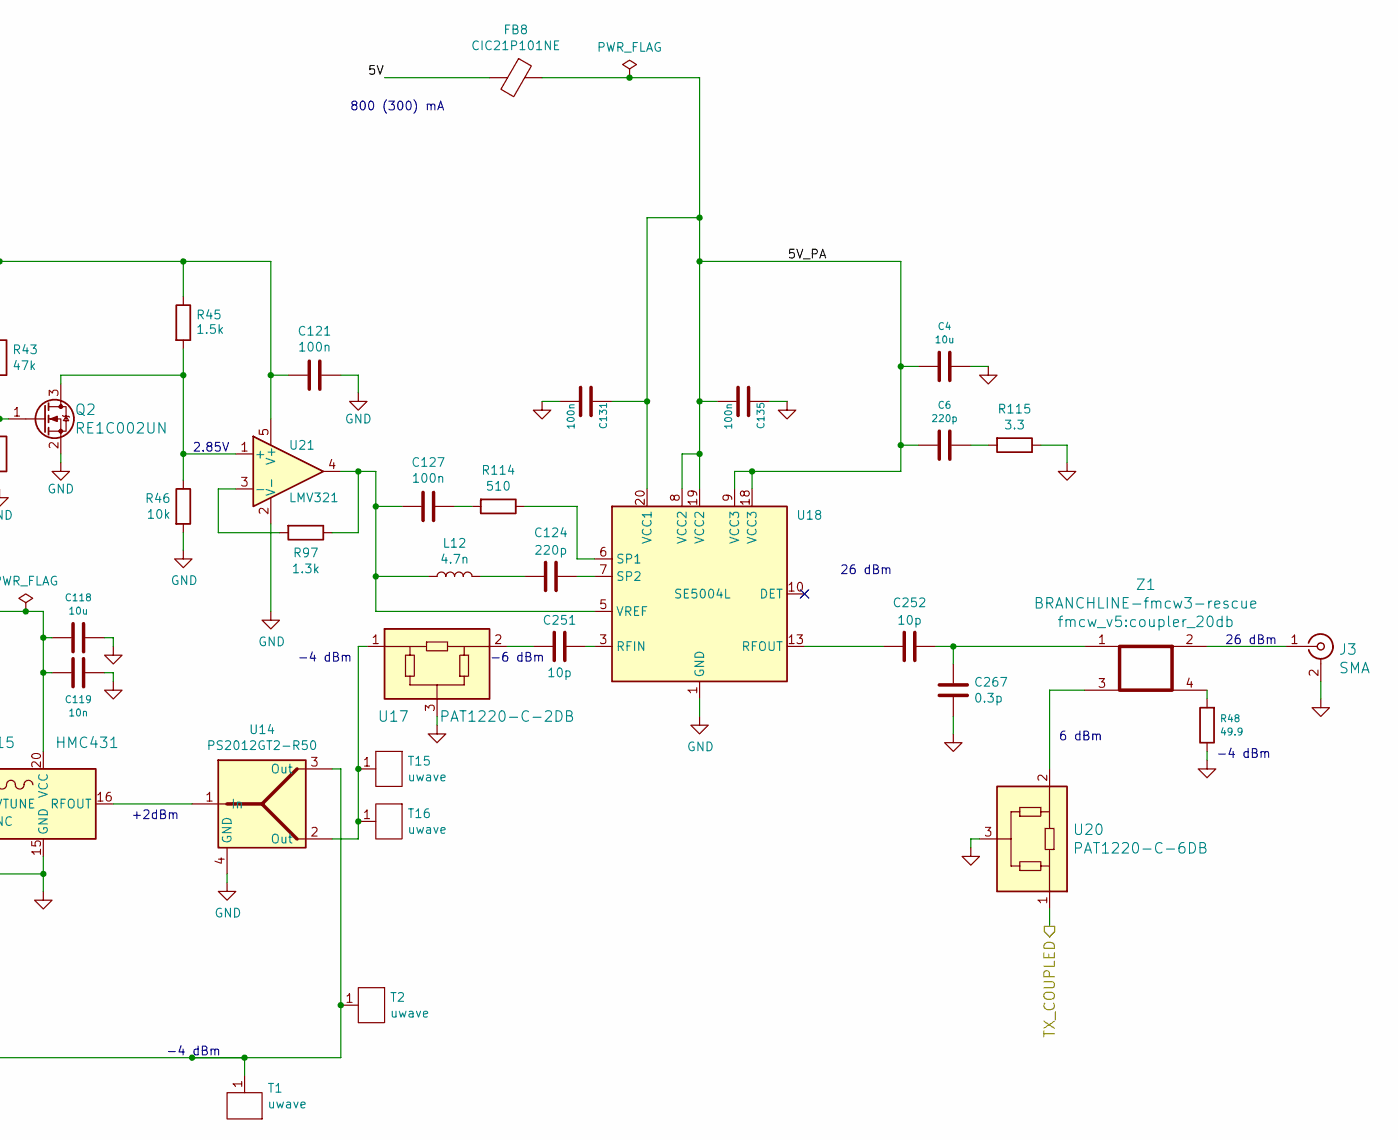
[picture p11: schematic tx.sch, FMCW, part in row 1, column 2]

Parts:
C4, C118: 10u; C_0805_2012Metric
C6, C124: 220p; C_0402_1005Metric
C102, C104, C105, C108, C115, C121, C127, C131, C135: 100n; C_0402_1005Metric
C103, C106, C107, C109: 10p; C_0402_1005Metric
C110: 2.2n; C_0402_1005Metric
C112, C251, C252: 10p; RF_C_0201_0603Metric
C113: DNP; C_0805_2012Metric
C114: 51p; C_0402_1005Metric
C119: 10n; C_0402_1005Metric
C120: 68p; C_0402_1005Metric
C267: 0.3p; RF_C_0201_0603Metric
FB6, FB7: BLM18PG181SH1D; L_0603_1608Metric
FB8: CIC21P101NE; L_0805_2012Metric
J3: SMA; BU-1420701851_SMA
L12: 4.7n; L_0402_1005Metric
Q2: RE1C002UN; SOT-416
R37: 5.49k; R_0402_1005Metric
R38, R44: DNP; R_0402_1005Metric
R39: 3.09k; R_0402_1005Metric
R40, R41, R42: 4.7k; R_0402_1005Metric
R43: 47k; R_0402_1005Metric
R45: 1.5k; R_0402_1005Metric
R46: 10k; R_0402_1005Metric
R48: 49.9; R_0402_1005Metric
R97: 1.3k; R_0402_1005Metric
R114: 510; R_0402_1005Metric
R115: 3.3; R_0402_1005Metric
T1, T2, T15, T16: uwave; uwm_0.38_0.17_90
U12: ADF4158; LFCSP-24-1EP_4x4mm_P0.5mm_EP2.5x2.5mm_ThermalVias
U13: TLV172DCK; SOT-353_SC-70-5
U14: PS2012GT2-R50; Susumu_PS2012GT2-R50
U15: HMC431; QFN-24-1EP_4x4mm_P0.5mm_EP2.8x2.8mm_ThermalVias
U17: PAT1220-C-2DB; RF_Attenuator_Susumu_PAT1220
U18: SE5004L; Skyworks_SE5004L
U20: PAT1220-C-6DB; RF_Attenuator_Susumu_PAT1220
U21: LMV321; SOT-23-5
Z1: BRANCHLINE-fmcw3-rescue; coupler_20db

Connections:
/3V0: FB7.2; also elsewhere on the board
/3V3A: C102.1, C103.1, C104.1, C105.1, C106.1, C121.2, R43.1, R45.1, U12.6 (AVDD), U12.7 (AVDD), U12.8 (AVDD), U12.18 (SDVDD), U12.19 (DVDD), U21.5 (V+); also elsewhere on the board
/5VPA: C113.1, FB6.2, FB8.2; also elsewhere on the board
/10V: C115.2, U13.5 (V+); also elsewhere on the board
/ADF_CE: U12.13 (CE); also elsewhere on the board
/ADF_CLK: U12.14 (CLK); also elsewhere on the board
/ADF_DATA: U12.15 (DATA); also elsewhere on the board
/ADF_LE: U12.16 (LE); also elsewhere on the board
/ADF_MUXOUT: U12.17 (MUXOUT); also elsewhere on the board
/ADF_REF: U12.9 (REFIN); also elsewhere on the board
/ADF_TXDATA: U12.12 (TXDATA); also elsewhere on the board
/LO: U20.1; also elsewhere on the board
/PA_OFF: Q2.1 (G), R43.2, R44.1; also elsewhere on the board
/tx/5V_PA: C4.2, C6.2, C131.1, C135.2, FB8.1, U18.8 (VCC2), U18.9 (VCC3), U18.18 (VCC3), U18.19 (VCC2), U18.20 (VCC1)
/tx/5V_SYNTH: C108.1, C109.1, FB6.1, U12.22 (VP)
GND: C4.1, C102.2, C103.2, C104.2, C105.2, C106.2, C107.1, C108.2, C109.2, C113.2, C114.2, C115.1, C118.1, C119.1, C120.2, C121.1, C131.2, C135.1, C267.1, J3.2 (Ext), Q2.2 (S), R37.2, R39.1, R40.2, R44.2, R46.2, R48.1, R115.1, U12.1 (CPGND), U12.2 (AGND), U12.3 (AGND), U12.10 (DGND), U12.11 (SDGND), U12.25 (AGND), U13.2 (V-), U14.4 (GND), U15.1 (NC), U15.2 (NC), U15.3 (NC), U15.4 (NC), U15.5 (NC), U15.6 (NC), U15.7 (NC), U15.8 (NC), U15.9 (NC), U15.10 (NC), U15.11 (NC), U15.12 (NC), U15.13 (NC), U15.14 (NC), U15.15 (GND), U15.17 (NC), U15.18 (NC), U15.19 (NC), U15.21 (NC), U15.23 (NC), U15.24 (NC), U15.25 (GND), U17.3, U18.1 (GND), U20.3, U21.2 (V-); also elsewhere on the board
unnamed: C6.1, R115.2
unnamed: C107.2, U12.4 (RFINB)
unnamed: C110.1, C114.1, U12.24 (CP), U13.1 (+)
unnamed: C110.2, R38.1, R39.2
unnamed: C112.1, T1.1, T2.1, U14.3 (Out)
unnamed: C112.2, U12.5 (RFINA)
unnamed: C118.2, C119.2, FB7.1, U15.20 (VCC)
unnamed: C120.1, R42.1, U15.22 (VTUNE)
unnamed: C124.1, U18.7 (SP2)
unnamed: C124.2, L12.2
unnamed: C127.1, R114.2
unnamed: C127.2, L12.1, R97.1, U18.5 (VREF), U21.4
unnamed: C251.1, U18.3 (RFIN)
unnamed: C251.2, U17.2
unnamed: C252.1, C267.2, Z1.1
unnamed: C252.2, U18.13 (RFOUT)
unnamed: J3.1 (In), Z1.2
unnamed: Q2.3 (D), R45.2, R46.1, U21.1 (+)
unnamed: R37.1, U12.23 (RSET)
unnamed: R38.2, U12.20 (SW1)
unnamed: R40.1, R41.2, U13.3 (-)
unnamed: R41.1, R42.2, U13.4
unnamed: R48.2, Z1.4
unnamed: R97.2, U21.3 (-)
unnamed: R114.1, U18.6 (SP1)
unnamed: T15.1, T16.1, U14.2 (Out), U17.1
unnamed: U14.1 (In), U15.16 (RFOUT)
unnamed: U20.2, Z1.3

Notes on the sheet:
32 (23) mA
5 mA
3 mA
27mA
10 mA
+2dBm
-4 dBm
2.85V
800 (300) mA
-6 dBm
26 dBm
6 dBm

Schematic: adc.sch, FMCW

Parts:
C75: 10u; C_0805_2012Metric
C76, C92, C93, C94: 2.2u; C_0603_1608Metric
C77, C84, C87, C88, C89, C90: 1u; C_0603_1608Metric
C78, C79, C80, C81, C82, C83: 100p; C_0402_1005Metric
C91, C95, C96, C97, C98, C99, C100, C101: 100n; C_0402_1005Metric
R28, R29, R30, R31: 49.9; R_0402_1005Metric
R32, R34, R35: 0; R_0402_1005Metric
R33: DNP; R_0402_1005Metric
R36: 22; R_0402_1005Metric
U10: LP5907MFX-3.0; SOT-23-5
U11: LTC2292; QFN-64-1EP_9x9mm_P0.5mm_EP7.15x7.15mm_ThermalVias

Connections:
/3V3D: C100.1, C101.1, U11.32 (OVDD), U11.49 (OVDD); also elsewhere on the board
/3V6: C75.1, U10.1 (IN), U10.3 (EN); also elsewhere on the board
/ADC1+: R31.2; also elsewhere on the board
/ADC1-: R29.2; also elsewhere on the board
/ADC2+: R30.2; also elsewhere on the board
/ADC2-: R28.2; also elsewhere on the board
/ADC_REF: R36.2, U11.8 (CLKA), U11.9 (CLKB); also elsewhere on the board
/ADC_VCM1: C92.2, U11.61 (VCMA); also elsewhere on the board
/ADC_VCM2: C76.1, U11.20 (VCMB); also elsewhere on the board
/fpga/ADC_OE1: U11.58 (~OEA); also elsewhere on the board
/fpga/ADC_OE2: U11.23 (~OEB); also elsewhere on the board
/fpga/ADC_SHDN1: U11.22 (SHDNB); also elsewhere on the board
/fpga/ADC_SHDN2: U11.59 (SHDNA); also elsewhere on the board
/fpga/D0: U11.43 (DA0); also elsewhere on the board
/fpga/D1: U11.44 (DA1); also elsewhere on the board
/fpga/D2: U11.45 (DA2); also elsewhere on the board
/fpga/D3: U11.46 (DA3); also elsewhere on the board
/fpga/D4: U11.47 (DA4); also elsewhere on the board
/fpga/D5: U11.48 (DA5); also elsewhere on the board
/fpga/D6: U11.51 (DA6); also elsewhere on the board
/fpga/D7: U11.52 (DA7); also elsewhere on the board
/fpga/D8: U11.53 (DA8); also elsewhere on the board
/fpga/D9: U11.54 (DA9); also elsewhere on the board
/fpga/D10: U11.55 (DA10); also elsewhere on the board
/fpga/D11: U11.56 (DA11); also elsewhere on the board
/fpga/OF1: U11.57 (OFA); also elsewhere on the board
/fpga/OF2: U11.40 (OFB); also elsewhere on the board
/fpga/adc/3V0: C77.1, C84.1, C91.1, C95.1, C98.1, C99.1, R32.1, R34.2, R35.2, U10.5 (OUT), U11.7 (VDD), U11.10 (VDD), U11.18 (VDD), U11.63 (VDD)
/fpga/adc/AINA+: C78.2, C79.1, R28.1, U11.1 (AINA+)
/fpga/adc/AINA-: C79.2, C80.1, R30.1, U11.2 (AINA-)
/fpga/adc/AINB+: C81.2, C82.1, R29.1, U11.16 (AINB+)
/fpga/adc/AINB-: C82.2, C83.1, R31.1, U11.15 (AINB-)
GND: C75.2, C76.2, C77.2, C78.1, C80.2, C81.1, C83.2, C84.2, C87.2, C88.2, C89.2, C90.2, C91.2, C92.1, C95.2, C98.2, C99.2, C100.2, C101.2, R33.2, U10.2 (GND), U11.17 (GND), U11.31 (OGND), U11.50 (OGND), U11.64 (GND), U11.65 (GND); also elsewhere on the board
unnamed: C87.1, C93.1, C96.1, U11.3 (REFHA), U11.4 (REFHA)
unnamed: C88.1, C93.2, C96.2, U11.5 (REFLA), U11.6 (REFLA)
unnamed: C89.1, C94.1, C97.1, U11.13 (REFHB), U11.14 (REFHB)
unnamed: C90.1, C94.2, C97.2, U11.11 (REFLB), U11.12 (REFLB)
unnamed: R32.2, R33.1, U11.60 (MODE)
unnamed: R34.1, U11.62 (SENSEA)
unnamed: R35.1, U11.19 (SENSEB)
unnamed: R36.1, U11.21 (MUX)

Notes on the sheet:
95 (78) mA
3 mA

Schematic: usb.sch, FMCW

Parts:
C59, C62, C63, C64, C65, C69, C70, C71, C72, C73, C74: 100n; C_0402_1005Metric
C60, C61: 15p; C_0402_1005Metric
C66, C67, C68: 4.7u; C_0603_1608Metric
FB3, FB4, FB5: BLM18PG181SH1D; L_0603_1608Metric
J2: USB_B_Micro; USB_Micro-B_Amphenol_10103594-0001LF_Horizontal
R3, R17, R27, R82: 10k; R_0402_1005Metric
R18: 2.2k; R_0402_1005Metric
R19: 12k; R_0402_1005Metric
R20, R21: 0; R_0402_1005Metric
R22: 1k; R_0402_1005Metric
R23, R24, R25: 33; R_0402_1005Metric
R26: 4.7k; R_0402_1005Metric
U8: 93LCxxBxxOT; SOT-23-6
U9: FT2232H; LQFP-64_10x10mm_P0.5mm
Y1: 12MHz; Crystal_SMD_Abracon_ABM10-4Pin_2.5x2.0mm

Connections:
/3V3D: FB3.2, FB4.1, FB5.1; also elsewhere on the board
/fpga/CLKOUT: U9.32 (ACBUS5); also elsewhere on the board
/fpga/FT_D0: U9.16 (ADBUS0); also elsewhere on the board
/fpga/FT_D1: U9.17 (ADBUS1); also elsewhere on the board
/fpga/FT_D2: U9.18 (ADBUS2); also elsewhere on the board
/fpga/FT_D3: U9.19 (ADBUS3); also elsewhere on the board
/fpga/FT_D4: U9.21 (ADBUS4); also elsewhere on the board
/fpga/FT_D5: U9.22 (ADBUS5); also elsewhere on the board
/fpga/FT_D6: U9.23 (ADBUS6); also elsewhere on the board
/fpga/FT_D7: U9.24 (ADBUS7); also elsewhere on the board
/fpga/FT_SUSPEND: U9.36 (~SUSPEND); also elsewhere on the board
/fpga/OE#: U9.33 (ACBUS6); also elsewhere on the board
/fpga/RD#: U9.28 (ACBUS2); also elsewhere on the board
/fpga/RXF#: U9.26 (ACBUS0); also elsewhere on the board
/fpga/SIWUA: U9.30 (ACBUS4); also elsewhere on the board
/fpga/TCK: R23.1; also elsewhere on the board
/fpga/TDI: R25.1; also elsewhere on the board
/fpga/TDO: U9.40 (BDBUS2); also elsewhere on the board
/fpga/TMS: R24.1; also elsewhere on the board
/fpga/TXE#: U9.27 (ACBUS1); also elsewhere on the board
/fpga/WR: U9.29 (ACBUS3); also elsewhere on the board
/fpga/usb/1V8: C62.1, C63.1, C64.1, C67.1, U9.12 (VCORE), U9.37 (VCORE), U9.49 (VREGOUT), U9.64 (VCORE)
/fpga/usb/3V3_IO: C59.1, C65.2, C71.1, C72.1, C73.1, C74.1, FB5.2, R3.1, R17.1, R22.2, R82.1, U8.6 (VCC), U9.20 (VCCIO), U9.31 (VCCIO), U9.42 (VCCIO), U9.50 (VREGIN), U9.56 (VCCIO)
/fpga/usb/DO: R17.2, R18.1, U8.1 (DO)
/fpga/usb/EECLK: R3.2, U8.4 (CLK), U9.62 (EECLK)
/fpga/usb/EECS: R82.2, U8.5 (CS), U9.63 (EECS)
/fpga/usb/EEDATA: R18.2, U8.3 (DI), U9.61 (EEDATA)
/fpga/usb/USBD_N: R20.1, U9.7 (DM)
/fpga/usb/USBD_P: R21.1, U9.8 (DP)
/fpga/usb/USBDa_N: J2.2 (D-), R20.2
/fpga/usb/USBDa_P: J2.3 (D+), R21.2
/fpga/usb/USB_5V: J2.1 (VBUS), R26.1
GND: C59.2, C60.2, C61.2, C62.2, C63.2, C64.2, C65.1, C66.2, C67.2, C68.2, C69.2, C70.2, C71.2, C72.2, C73.2, C74.2, J2.5 (GND), J2.6 (Shield), R19.2, R27.2, U8.2 (GND), U9.1 (GND), U9.5 (GND), U9.10 (AGND), U9.11 (GND), U9.13 (TEST), U9.15 (GND), U9.25 (GND), U9.35 (GND), U9.47 (GND), U9.51 (GND); also elsewhere on the board
unnamed: C60.1, U9.2 (OSCI), Y1.1
unnamed: C61.1, U9.3 (OSCO), Y1.3
unnamed: C66.1, C69.1, FB4.2, U9.4 (VPHY)
unnamed: C68.1, C70.1, FB3.1, U9.9 (VPLL)
unnamed: R19.1, U9.6 (REF)
unnamed: R22.1, U9.14 (~RESET)
unnamed: R23.2, U9.38 (BDBUS0)
unnamed: R24.2, U9.41 (BDBUS3)
unnamed: R25.2, U9.39 (BDBUS1)
unnamed: R26.2, R27.1, U9.59 (BCBUS7)

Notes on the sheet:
70 mA
150 mA

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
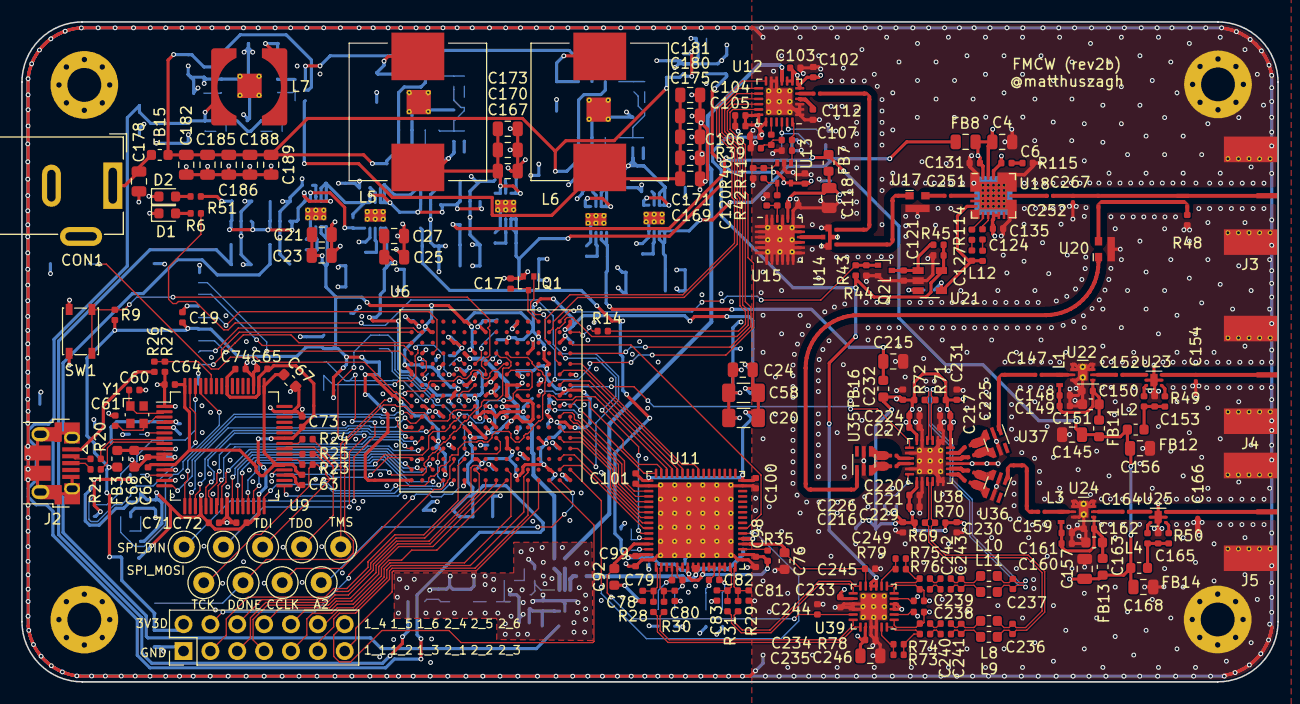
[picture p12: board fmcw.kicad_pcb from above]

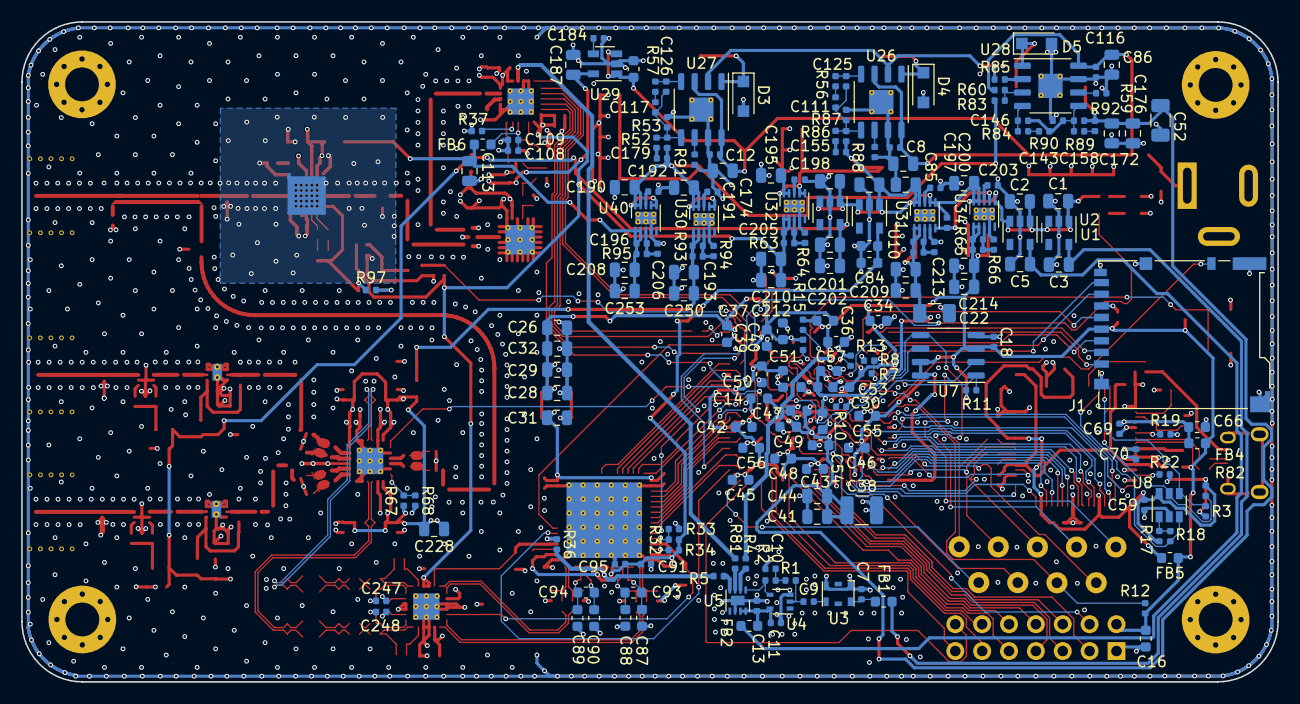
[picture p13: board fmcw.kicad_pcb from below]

Board: 4 copper layers, 118.8 x 62.4 mm, 445 parts (196 on the bottom side), 265 nets.

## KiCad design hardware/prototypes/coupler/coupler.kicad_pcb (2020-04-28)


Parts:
J1, J2, J3, J4: Conn_Coaxial; BU-1420701851_SMA
Z1: BRANCHLINE; coupler_20db

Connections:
GND: J1.2 (Ext), J2.2 (Ext), J3.2 (Ext), J4.2 (Ext)
unnamed: J1.1 (In), Z1.1
unnamed: J2.1 (In), Z1.3
unnamed: J3.1 (In), Z1.2
unnamed: J4.1 (In), Z1.4


Board: 4 copper layers, 36.0 x 24.0 mm, 5 parts (0 on the bottom side), 5 nets.

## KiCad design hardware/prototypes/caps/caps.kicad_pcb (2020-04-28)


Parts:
C1: 10p; RF_C_0201_0603Metric
C2: 10p; RF_C_0402_1005Metric
C3: 0.5p; RF_C_0201_0603Metric
J1, J2, J3, J4, J5, J6, J7, J8: Conn_Coaxial; SMA_901-10512

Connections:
GND: C3.1, J1.2 (Ext), J2.2 (Ext), J3.2 (Ext), J4.2 (Ext), J5.2 (Ext), J6.2 (Ext), J7.2 (Ext), J8.2 (Ext)
unnamed: C1.1, J2.1 (In)
unnamed: C1.2, J6.1 (In)
unnamed: C2.1, J3.1 (In)
unnamed: C2.2, J7.1 (In)
unnamed: C3.2, J4.1 (In), J8.1 (In)
unnamed: J1.1 (In), J5.1 (In)

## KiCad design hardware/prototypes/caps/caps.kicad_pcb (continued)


Board: 4 copper layers, 30.0 x 72.8 mm, 11 parts (0 on the bottom side), 7 nets.

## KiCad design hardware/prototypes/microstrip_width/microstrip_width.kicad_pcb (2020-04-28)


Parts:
J1, J2, J3, J4, J5, J6: Conn_Coaxial; BU-1420701851_SMA

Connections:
GND: J1.2 (Ext), J2.2 (Ext), J3.2 (Ext), J4.2 (Ext), J5.2 (Ext), J6.2 (Ext)
unnamed: J1.1 (In), J4.1 (In)
unnamed: J2.1 (In), J5.1 (In)
unnamed: J3.1 (In), J6.1 (In)


Board: 4 copper layers, 30.0 x 46.9 mm, 6 parts (0 on the bottom side), 4 nets.

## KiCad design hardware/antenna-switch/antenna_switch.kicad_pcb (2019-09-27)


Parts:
C85, C86, C125, C126, C143, C146, C155, C158, C167, C192: 22p; C_0402_1005Metric
C111, C193: 1u; C_0603_1608Metric
C117, C250: 10n; C_0402_1005Metric
H4, H5, H6, H7: MountingHole_Pad; MountingHole_2.5mm_Pad_Via
J8: Conn_01x04; PinHeader_1x04_P2.54mm_Vertical
RCF1, RCF2: Conn_Coaxial; CONSMA003.062
RXa1, RXa2, RXa3, RXa4: Conn_Coaxial; CONSMA003.062
RXb1, RXb2, RXb3, RXb4: Conn_Coaxial; CONSMA003.062
U40: SN74LVC2G14; SOT-23-6
U41, U42: HMC7992; LFCSP-16-1EP_3x3mm_P0.5mm_EP1.7x1.7mm

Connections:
/RF Switch/A: J8.3, U40.3 (2A), U42.8 (A)
/RF Switch/B: J8.4, U40.1 (1A), U42.7 (B)
GND: C111.1, C117.1, C193.1, C250.1, H4.1, H5.1, H6.1, H7.1, J8.1, RCF1.2 (Ext), RCF2.2 (Ext), RXa1.2 (Ext), RXa2.2 (Ext), RXa3.2 (Ext), RXa4.2 (Ext), RXb1.2 (Ext), RXb2.2 (Ext), RXb3.2 (Ext), RXb4.2 (Ext), U40.2 (GND), U41.2 (GND), U41.3 (GND), U41.5 (GND), U41.10 (GND), U41.11 (GND), U41.13 (GND), U41.14 (GND), U41.16 (GND), U41.17 (GND), U42.2 (GND), U42.3 (GND), U42.5 (GND), U42.10 (GND), U42.11 (GND), U42.13 (GND), U42.14 (GND), U42.16 (GND), U42.17 (GND)
unnamed: C85.1, U42.15 (RFC)
unnamed: C85.2, RCF1.1 (In)
unnamed: C86.1, U41.15 (RFC)
unnamed: C86.2, RCF2.1 (In)
unnamed: C125.1, RXb4.1 (In)
unnamed: C125.2, U41.12 (RF1)
unnamed: C126.1, RXa2.1 (In)
unnamed: C126.2, U42.9 (RF2)
unnamed: C143.1, RXb2.1 (In)
unnamed: C143.2, U41.4 (RF3)
unnamed: C146.1, RXa4.1 (In)
unnamed: C146.2, U42.1 (RF4)
unnamed: C155.1, RXa1.1 (In)
unnamed: C155.2, U42.12 (RF1)
unnamed: C158.1, RXb1.1 (In)
unnamed: C158.2, U41.1 (RF4)
unnamed: C167.1, RXa3.1 (In)
unnamed: C167.2, U42.4 (RF3)
unnamed: C192.1, RXb3.1 (In)
unnamed: C192.2, U41.9 (RF2)
unnamed: U40.4 (2Y), U41.8 (A)
unnamed: U40.6 (1Y), U41.7 (B)
VDD: C111.2, C117.2, C193.2, C250.2, J8.2, U40.5 (VCC), U41.6 (VDD), U42.6 (VDD)



Board: 4 copper layers, 45.2 x 53.3 mm, 32 parts (14 on the bottom side), 26 nets.

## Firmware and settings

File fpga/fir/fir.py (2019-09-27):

#!/usr/bin/env python2
"""Finite-impulse response filter."""

from scipy import signal
import bitstring
import matplotlib.pyplot as plt
import numpy as np
import math


class FIR:
    """Finite-impulse response filter."""

    def __init__(self, numtaps, bands, band_gain, fs, pass_db=1, stop_db=-40):
        w = [1 / (1 - 10 ** (-pass_db / 20)), 1 / (10 ** (stop_db / 20))]
        self.fs = fs
        self.taps = signal.remez(
            numtaps=numtaps,
            bands=bands,
            desired=band_gain,
            weight=w,
            fs=fs,
            type="bandpass",
        )

    def quantize_2s_comp(self, nbits, val, max_val=1):
        """Quantize a real number (val) for two's complement representation
        using a supplied number of bits (nbits). The original range of
        values is [-max_val, max_val].

        """
        norm_val = val / max_val
        return round(norm_val * 2 ** (nbits - 1))

    def quantized_taps(self, nbits, taps=None):
        """Quantize all taps for two's complement representation with `nbits'
        bits. This assumes a tap value range of [-1,1]. If you do not
        provide taps, this uses self.taps.

        """
        if taps is None:
            taps = self.taps

        new_taps = np.zeros(len(taps))
        for i in range(len(taps)):
            new_taps[i] = self.quantize_2s_comp(nbits, taps[i]) / 2 ** (
                nbits - 1
            )
        return new_taps

    def as_hex(self, nbits, taps=None):
        """
        FIR tap array in hexadecimal representation using `nbits'
        bits.

        When using this for synthesis, you should only provide a
        number of bits that is a multiple of 4. Other values can lead
        to unexpected errors.
        """
        if taps is None:
            taps = self.taps

        # TODO this is necessary due to the limitations of
        # bitstring. This should be rewritten to support non-multiples
        # of 4.
        if nbits % 4 != 0:
            nbits = int(4 * math.ceil(nbits / 4))

        hex_taps = []
        for elt in taps:
            bit_val = self.quantize_2s_comp(nbits, elt)
            hex_taps.append(
                bitstring.BitArray(int=int(bit_val), length=nbits).hex
            )
        return hex_taps

    def as_dec(self, nbits, taps=None):
        """Similar to as hex, but generates decimal output."""
        if taps is None:
            taps = self.taps

        new_taps = []
        for tap in taps:
            val = self.quantize_2s_comp(nbits, tap)
            new_taps.append(val)
            # if elt < 0:
            #     val = int(elt * 2 ** (nbits - 1))
            #     new_seq.append(val)
            # else:
            #     val = int(elt * 2 ** (nbits - 1) - 1)
            #     new_seq.append(val)

        return new_taps

    def gen_input_sample(self, length):
        """Create dummy input sample for testing."""
        sample_times = np.linspace(0, self.fs * length, length + 1)
        sig = 0
        for i in range(1, 101):
            sig += np.sin(sample_times * self.fs / i)
        sig /= np.max(np.absolute(sig))
        return sig

    def dummy_in_out(self, nbits):
        signal = self.gen_input_sample(10000)
        signal *= 2 ** (nbits - 1)
        output = np.convolve(signal, self.taps, mode="same")
        for i in range(len(output)):
            if i % 20 == 0:
                print("{:5d} {:5d}".format(int(signal[i]), int(output[i])))
            else:
                print("{:5d}".format(int(signal[i])))

    def write_input_sample_file(
        self,
        length,
        downsample_factor,
        nbits_in,
        nbits_out,
        dirs,
        include_outputs=True,
    ):
        """Write sample (and optionally) decimated outputs to a file."""
        sig = self.gen_input_sample(length)
        sig_hex = self.as_hex(nbits_in, taps=sig)
        if include_outputs:
            outputs = signal.resample_poly(
                sig, 1, downsample_factor, 0, self.taps
            )
            out_hex = self.as_hex(nbits_out, taps=outputs)

            # manually computed outputs
            man_out = []
            man_out = np.convolve(sig, self.taps)

            man_out_decimated = [
                man_out[i] for i in range(len(man_out)) if i % 20 == 0
            ]

            for d in dirs:
                path_in_hex = d + "sample_in.hex"
                with open(path_in_hex, "w") as f:
                    for val_hex in sig_hex:
                        f.write("{}\n".format(val_hex))
                path_in = d + "sample_in.txt"
                with open(path_in, "w") as f:
                    for val in sig:
                        f.write("{}\n".format(int(val * 2 ** (nbits_in - 1))))
                path_out_hex = d + "sample_out.hex"
                with open(path_out_hex, "w") as f:
                    for val_hex in out_hex:
                        f.write("{}\n".format(val_hex))
                path_out = d + "sample_out.txt"
                with open(path_out, "w") as f:
                    for val in outputs:
                        f.write("{}\n".format(int(val * 2 ** (nbits_in - 1))))
                path_out_manual = d + "sample_out_manual.txt"
                with open(path_out_manual, "w") as f:
                    for val in man_out_decimated:
                        f.write(
                            "{:8d} {:8.2f}\n".format(
                                int(val * 2 ** (nbits_in - 1)),
                                val * 2 ** (nbits_in - 1),
                            )
                        )

        else:
            for d in dirs:
                path_in = d + "sample_in.hex"
                with open(path_in, "w") as f:
                    for val_hex in sig_hex:
                        f.write("{}\n".format(val_hex))

    def plot_samples(
        self, sim_out_path, length, nbits_in, nbits_out, downsample_factor
    ):
        """Compare plot of input samples, numpy decimation and testbench
        output."""
        sig = self.gen_input_sample(length)
        sig_dec = self.as_dec(nbits_in, seq=sig)
        scipy_outputs = signal.resample_poly(
            sig, 1, downsample_factor, 0, self.taps
        )
        scipy_out_dec = self.as_dec(nbits_out, seq=scipy_outputs)
        sim_out = []
        with open(sim_out_path, "r") as f:
            for cnt, line in enumerate(f):
                line = line.strip(" \nx")
                if line:
                    sim_out.append(int(line))

        # x_orig = np.linspace(0)
        # x_decimate = np.linspace

    def output_bit_width(self, nbits):
        """Compute the number of output bits needed to represent every
        result. `nbits' is the number of bits in each input
        sample. This function takes the most pessimistic possible view
        of the input samples. Specifically, that all negative taps are
        multiplied by the most negative possible input and all
        positive taps are multiplied by the most positive possible
        input."""
        max_input = 2 ** (nbits - 1) - 1
        min_input = -2 ** (nbits - 1)
        output = 0
        for tap in self.taps:
            if tap < 0:
                output += tap * min_input
            else:
                output += tap * max_input

        output_bits = int(np.ceil(np.log2(output + 1) + 1))
        return output_bits

    def tap_normalization_shift(self, taps=None):
        """Compute a normalization factor that can be used to make more
        efficient use of bits for the taps. Tap abs(values) are often
        much less than 1, so if we assume they range from -1 to 1 we
        waste a lot of bits representing values that can never
        exist. This function finds a factor power of 2 (for easy bit
        shifts) that scales each tap to fill more of the range
        [-1,1]. To get the right result at the end, simply right shift
        by this amount.

        """
        if taps is None:
            taps = self.taps

        max_tap = np.max(np.abs(taps))
        factor = 1 / max_tap
        return int(np.floor(np.log2(factor)))

    def normalized_taps(self, taps=None):
        """Scale all taps by the shift returned by
        `tap_normalization_shift'.

        """
        if taps is None:
            taps = self.taps

        factor = 2 ** self.tap_normalization_shift(taps=taps)
        new_taps = np.zeros(len(taps))
        for i in range(len(taps)):
            new_taps[i] = factor * taps[i]
        return new_taps

    def write_taps_file(self, paths, nbits):
        """Write taps in hex format to each file specified in path."""
        fir_hex = self.as_hex(nbits, use_taps=True)
        for path in paths:
            with open(path, "w") as f:
                for val in fir_hex:
                    f.write("{}\n".format(val))

    def write_poly_taps_files(
        self, dirs, nbits, downsample_factor, normalize_taps=True
    ):
        """Write taps separated into polyphase components. Each polyphase
        filter is written to its own file. This method uses normalized
        taps by default for more efficient bit representation. Note
        that if you use normalized taps you must scale the result by
        the normalization factor. See `normalization_shift' for the
        factor.

        """
        if normalize_taps:
            fir_hex = self.as_hex(nbits, taps=self.normalized_taps())
        else:
            fir_hex = self.as_hex(nbits)

        for d in dirs:
            for filt in range(0, downsample_factor, 2):
                path = d + "taps" + str(filt) + "_" + str(filt + 1) + ".hex"
                with open(path, "w") as f:
                    i = 0
                    for val in fir_hex:
                        if i % downsample_factor == filt:
                            f.write("{}\n".format(val))
                        i += 1
                    # TODO this is not properly parameterized
                    for _ in range(4):
                        f.write("0000\n")
                    i = 0
                    for val in fir_hex:
                        if i % downsample_factor == filt + 1:
                            f.write("{}\n".format(val))
                        i += 1
                    for _ in range(4):
                        f.write("0000\n")

    def pass_ripple(self, taps, band, fs):
        """Compute peak passband ripple for an FIR filter specified by its
        taps. band is the bandpass region, which must a list of 2
        elements for the start and end of the region, respectively. fs
        is the sampling frequency.

        """
        num_freqs = 1024
        freqs, resp = signal.freqz(taps, [1], worN=num_freqs, fs=fs)
        fn = fs / 2
        delta_f = fn / num_freqs
        band_low = band[0]
        band_high = band[1]

        max_ripple = 0
        for i in range(len(freqs)):
            freq = freqs[i]
            if band_low <= freq <= band_high:
                gain_db = 20 * np.log10(np.abs(resp[i]))
                ripple = np.abs(gain_db)
                if ripple > max_ripple:
                    max_ripple = ripple

        return max_ripple

    def plot_response(self, savefile, taps=None):
        """Utility function to plot response functions."""
        if taps is None:
            taps = self.taps

        fig = plt.figure()
        ax = fig.add_subplot(111)
        w, h = signal.freqz(taps, [1], worN=1024)
        ax.plot(0.5 * self.fs * w / np.pi, 20 * np.log10(np.abs(h)))
        ax.set_ylim(-80, 5)
        ax.set_xlim(0, 0.1 * self.fs)
        ax.grid(True)
        ax.set_xlabel("Frequency (Hz)")
        ax.set_ylabel("Gain (dB)")
        ax.set_title("FIR Response")
        # fig.show()
        fig.savefig(savefile)


if __name__ == "__main__":
    NUMTAPS = 1200
    FS = 40e6
    FN = FS / 2
    BANDS = [0, 0.95e6, 1e6, FN]
    BAND_GAIN = [1, 0]
    FIR = FIR(NUMTAPS, BANDS, BAND_GAIN, FS, pass_db=0.5)

    max_tap = np.max(np.abs(FIR.taps))
    factor = int(np.floor(np.log2(1 / max_tap)))
    print(factor)
    normalized_taps = 2 ** factor * FIR.taps
    for i in range(len(normalized_taps)):
        if normalized_taps[i] < -1:
            normalized_taps[i] = -1
        elif normalized_taps[i] > 1:
            normalized_taps[i] = 1

    quantized_taps = FIR.quantized_taps(10, taps=normalized_taps) / 2 ** factor
    FIR.plot_response("plot_response_quant.png", taps=quantized_taps)

    # avg = np.average(FIR.taps)
    # factor = int(np.floor(np.log2(1 / avg)))
    # new_taps = FIR.taps * 2 ** factor
    # for tap in new_taps:
    #     print(tap)
    # n_pts = 1000
    # plt.hist(taps, bins=n_pts)
    # plt.show()
    # FIR.plot_response()

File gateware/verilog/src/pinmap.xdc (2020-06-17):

create_clock -period 25.000 -name clk_i -waveform {0.000 12.500} [get_ports clk_i]
create_clock -period 16.667 -name ft_clkout_i -waveform {0.000 8.333} [get_ports ft_clkout_i]
# set_output_delay -clock ft_clkout_i -max 8 [get_ports ft_data_io]

set_clock_groups -asynchronous -group [get_clocks clk_i -include_generated_clocks]
set_clock_groups -asynchronous -group [get_clocks ft_clkout_i -include_generated_clocks]

set_property CLOCK_DEDICATED_ROUTE FALSE [get_nets ft_clkout_i_IBUF]
# set_property CLOCK_DEDICATED_ROUTE FALSE [get_nets ext1_io_IBUF[0]]

set_property CONFIG_VOLTAGE 3.3 [current_design]
set_property CFGBVS VCCO [current_design]

set_property -dict {IOSTANDARD LVCMOS33 PACKAGE_PIN N11} [get_ports clk_i]
set_property -dict {IOSTANDARD LVCMOS33 PACKAGE_PIN D1} [get_ports led_o]
set_property -dict {IOSTANDARD LVCMOS33 PACKAGE_PIN C11} [get_ports ext1_io[0]]
set_property -dict {IOSTANDARD LVCMOS33 PACKAGE_PIN B10} [get_ports ext1_io[1]]
set_property -dict {IOSTANDARD LVCMOS33 PACKAGE_PIN A9} [get_ports ext1_io[2]]
set_property -dict {IOSTANDARD LVCMOS33 PACKAGE_PIN C12} [get_ports ext1_io[3]]
set_property -dict {IOSTANDARD LVCMOS33 PACKAGE_PIN B9} [get_ports ext1_io[4]]
set_property -dict {IOSTANDARD LVCMOS33 PACKAGE_PIN A8} [get_ports ext1_io[5]]
set_property -dict {IOSTANDARD LVCMOS33 PACKAGE_PIN B7} [get_ports ext2_io[0]]
set_property -dict {IOSTANDARD LVCMOS33 PACKAGE_PIN A5} [get_ports ext2_io[1]]
set_property -dict {IOSTANDARD LVCMOS33 PACKAGE_PIN A4} [get_ports ext2_io[2]]
set_property -dict {IOSTANDARD LVCMOS33 PACKAGE_PIN A7} [get_ports ext2_io[3]]
set_property -dict {IOSTANDARD LVCMOS33 PACKAGE_PIN B5} [get_ports ext2_io[4]]
set_property -dict {IOSTANDARD LVCMOS33 PACKAGE_PIN A3} [get_ports ext2_io[5]]

set_property -dict {IOSTANDARD LVCMOS33 PACKAGE_PIN F15} [get_ports ft_data_io[0]]
set_property -dict {IOSTANDARD LVCMOS33 PACKAGE_PIN G16} [get_ports ft_data_io[1]]
set_property -dict {IOSTANDARD LVCMOS33 PACKAGE_PIN G15} [get_ports ft_data_io[2]]
set_property -dict {IOSTANDARD LVCMOS33 PACKAGE_PIN F14} [get_ports ft_data_io[3]]
set_property -dict {IOSTANDARD LVCMOS33 PACKAGE_PIN E16} [get_ports ft_data_io[4]]
set_property -dict {IOSTANDARD LVCMOS33 PACKAGE_PIN E15} [get_ports ft_data_io[5]]
set_property -dict {IOSTANDARD LVCMOS33 PACKAGE_PIN D16} [get_ports ft_data_io[6]]
set_property -dict {IOSTANDARD LVCMOS33 PACKAGE_PIN D15} [get_ports ft_data_io[7]]
set_property -dict {IOSTANDARD LVCMOS33 PACKAGE_PIN B16} [get_ports ft_rxf_n_i]
set_property -dict {IOSTANDARD LVCMOS33 PACKAGE_PIN B15} [get_ports ft_txe_n_i]
set_property -dict {IOSTANDARD LVCMOS33 PACKAGE_PIN B14} [get_ports ft_rd_n_o]
set_property -dict {IOSTANDARD LVCMOS33 PACKAGE_PIN A14} [get_ports ft_wr_n_o]
set_property -dict {IOSTANDARD LVCMOS33 PACKAGE_PIN A13} [get_ports ft_siwua_n_o]
set_property -dict {IOSTANDARD LVCMOS33 PACKAGE_PIN A15} [get_ports ft_clkout_i]
# set_property -dict {IOSTANDARD LVCMOS33 PACKAGE_PIN D13} [get_ports ft_clkout_i]
set_property -dict {IOSTANDARD LVCMOS33 PACKAGE_PIN A12} [get_ports ft_oe_n_o]
set_property -dict {IOSTANDARD LVCMOS33 PACKAGE_PIN C16} [get_ports ft_suspend_n_i]

set_property -dict {IOSTANDARD LVCMOS33 PACKAGE_PIN L2} [get_ports adc_d_i[0]]
set_property -dict {IOSTANDARD LVCMOS33 PACKAGE_PIN K2} [get_ports adc_d_i[1]]
set_property -dict {IOSTANDARD LVCMOS33 PACKAGE_PIN K1} [get_ports adc_d_i[2]]
set_property -dict {IOSTANDARD LVCMOS33 PACKAGE_PIN J3} [get_ports adc_d_i[3]]
set_property -dict {IOSTANDARD LVCMOS33 PACKAGE_PIN H1} [get_ports adc_d_i[4]]
set_property -dict {IOSTANDARD LVCMOS33 PACKAGE_PIN H2} [get_ports adc_d_i[5]]
set_property -dict {IOSTANDARD LVCMOS33 PACKAGE_PIN H3} [get_ports adc_d_i[6]]
set_property -dict {IOSTANDARD LVCMOS33 PACKAGE_PIN G2} [get_ports adc_d_i[7]]
set_property -dict {IOSTANDARD LVCMOS33 PACKAGE_PIN G1} [get_ports adc_d_i[8]]
set_property -dict {IOSTANDARD LVCMOS33 PACKAGE_PIN F2} [get_ports adc_d_i[9]]
set_property -dict {IOSTANDARD LVCMOS33 PACKAGE_PIN E1} [get_ports adc_d_i[10]]
set_property -dict {IOSTANDARD LVCMOS33 PACKAGE_PIN E2} [get_ports adc_d_i[11]]
set_property -dict {IOSTANDARD LVCMOS33 PACKAGE_PIN C2} [get_ports adc_of_i[0]]
set_property -dict {IOSTANDARD LVCMOS33 PACKAGE_PIN M1} [get_ports adc_of_i[1]]
set_property -dict {IOSTANDARD LVCMOS33 PACKAGE_PIN B2} [get_ports adc_oe_o[0]]
set_property -dict {IOSTANDARD LVCMOS33 PACKAGE_PIN P1} [get_ports adc_oe_o[1]]
set_property -dict {IOSTANDARD LVCMOS33 PACKAGE_PIN B1} [get_ports adc_shdn_o[0]]
set_property -dict {IOSTANDARD LVCMOS33 PACKAGE_PIN N2} [get_ports adc_shdn_o[1]]
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

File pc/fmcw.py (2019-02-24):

#!/usr/bin/python

import pylibftdi as ftdi
from adf4158 import ADF4158
from queue import Queue, Empty
from threading import Thread
import datetime
import keyboard
import os


class FMCW():
    """Interface to the FMCW radar."""

    def __init__(self):
        SYNCFF = 0x40  # Configures bit-bang mode for synchronous FIFO.
        SIO_RTS_CTS_HS = (0x1 << 8)
        self.device = ftdi.Device(mode='t', interface_select=ftdi.INTERFACE_A)
        self.device.open()
        self.device.ftdi_fn.ftdi_set_bitmode(0xff, SYNCFF)
        self.device.ftdi_fn.ftdi_read_data_set_chunksize(0x10000)
        self.device.ftdi_fn.ftdi_write_data_set_chunksize(0x10000)
        self.device.ftdi_fn.ftdi_setflowctrl(SIO_RTS_CTS_HS)
        self.device.flush()

        self.pll = ADF4158()
        self.fclk = 40e6
        self.fpd_freq = self.fclk/2

    def close(self):
        self.device.close()
        return

    def send_packet(self, x, cmd):
        try:
            l = len(x)
        except TypeError:
            l = 1
            x = [x]

        header = [0xaa, l, cmd]
        b = bytearray(header+x)
        # print map(hex, map(ord, str(b)))
        return self.device.write(b)

    def clear_gpio(self, led=False, pa_off=False, mix_enbl=False, adf_ce=False):
        w = 0
        if led:
            w |= 1 << 0
        if pa_off:
            w |= 1 << 1
        if mix_enbl:
            w |= 1 << 2
        if adf_ce:
            w |= 1 << 3
        return self.send_packet(w, 0)

    def set_gpio(self, led=False, pa_off=False, mix_enbl=False, adf_ce=False):
        w = 0
        if led:
            w |= 1 << 0
        if pa_off:
            w |= 1 << 1
        if mix_enbl:
            w |= 1 << 2
        if adf_ce:
            w |= 1 << 3
        return self.send_packet(w, 1)

    def clear_adc(self, oe1=False, oe2=False, shdn1=False, shdn2=False):
        w = 0
        if oe1:
            w |= 1 << 0
        if oe2:
            w |= 1 << 1
        if shdn1:
            w |= 1 << 2
        if shdn2:
            w |= 1 << 3
        return self.send_packet(w, 2)

    def set_adc(self, oe1=False, oe2=False, shdn1=False, shdn2=False):
        w = 0
        if oe1:
            w |= 1 << 0
        if oe2:
            w |= 1 << 1
        if shdn1:
            w |= 1 << 2
        if shdn2:
            w |= 1 << 3
        return self.send_packet(w, 3)

    def write_pll_reg(self, n):
        reg = self.pll.registers[n]
        w = [(reg & 0xff) | n, (reg >> 8) & 0xff,
             (reg >> 16) & 0xff, (reg >> 24) & 0xff]
        return self.send_packet(w, 4)

    def write_pll(self):
        self.write_pll_reg(7)
        self.pll.write_value(step_sel=0)
        self.write_pll_reg(6)
        self.pll.write_value(step_sel=1)
        self.write_pll_reg(6)
        self.pll.write_value(dev_sel=0)
        self.write_pll_reg(5)
        self.pll.write_value(dev_sel=1)
        self.write_pll_reg(5)
        for i in range(4, -1, -1):
            self.write_pll_reg(i)

    def set_sweep(self, fstart, bw, length, delay):
        real_delay = self.pll.freq_to_regs(
            fstart, self.fpd_freq, bw, length, delay)
        self.write_pll()
        return real_delay

    def write_sweep_timer(self, length):
        length = int(self.fclk*length)
        w = [(length & 0xff), (length >> 8) & 0xff,
             (length >> 16) & 0xff, (length >> 24) & 0xff]
        return self.send_packet(w, 5)

    def write_sweep_delay(self, length):
        length = int(self.fclk*length)
        w = [(length & 0xff), (length >> 8) & 0xff,
             (length >> 16) & 0xff, (length >> 24) & 0xff]
        return self.send_packet(w, 6)

    def set_channels(self, a=True, b=True):
        w = 0
        if a:
            w |= 1 << 0
        if b:
            w |= 1 << 1
        return self.send_packet(w, 7)

    def set_downsampler(self, enable=True, quarter=False):
        w = 0
        if enable:
            w |= 1 << 0
        if quarter:
            w |= 1 << 1
        return self.send_packet(w, 8)

    def write_decimate(self, decimate):
        if decimate > 2**16-1 or decimate < 1:
            raise ValueError("Invalid decimate value")
        decimate = int(decimate) - 1
        w = [decimate & 0xff, (decimate >> 8) & 0xff]
        return self.send_packet(w, 9)

    def write_pa_off_timer(self, length):
        length = int(self.fclk*length)
        w = [(length & 0xff), (length >> 8) & 0xff,
             (length >> 16) & 0xff, (length >> 24) & 0xff]
        return self.send_packet(w, 10)

    def clear_buffer(self):
        return self.send_packet(0, 11)


class Writer(Thread):
    def __init__(self, filename, queue):
        Thread.__init__(self)
        self.queue = queue
        self.f = open(filename, 'w')

    def run(self):
        wrote = 0
        while True:
            try:
                d = self.queue.get(True, 0.5)
            except Empty:
                print('Timeout', wrote)
                self.f.close()
                return
            if len(d) == 0:
                print('Closed', wrote)
                self.f.close()
                return
            else:
                self.f.write(d)
                wrote += len(d)
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

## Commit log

2017-09-27 Fix FPGA programming resistor connections
    M[2:0] were wired incorrectly when I ordered the board. For programming from SPI
    memory M[2:0] should be "001", but I had them wired backwards as "100". I fixed
    it with one jump wire, but here is a proper fix for anyone looking to reproduce
    the design.
    [fmcw3.kicad_pcb, fpga.sch]
2018-10-06 Current working version.
    [adc.sch, fmcw3.csv, fmcw3.kicad_pcb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]
2018-10-10 Dropped the 3 from the end of the project name.
    [adc.sch, fmcw.kicad_pcb, fmcw.sch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]
2018-12-11 Modularized LaTeX documentation.
    [adc.sch, fmcw.kicad_pcb, fmcw.sch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]
2018-12-18 Adjusted power supply for new power amplifier.
    [adc.sch, fmcw.sch, fpga.sch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]
2018-12-20 Documentation for TPS5420D buck converter.
    [adc.sch, fmcw.kicad_pcb, fmcw.sch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]
2018-12-26 Made some modifications to the power hardware.
    [mixer.sch, power.sch]
2018-12-30 Improved top level documentation.
    [adc.sch, fmcw.sch, if.sch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]
2019-01-04 Added MFNs to components.
    [adc.sch, fmcw.kicad_pcb, fmcw.sch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]
2019-01-04 Fixed ERC errors.
    [fmcw.kicad_pcb, fmcw.sch, fpga.sch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]
2019-01-08 Improved documentation and added schematics to default libraries.
    [adc.sch, fmcw.sch, fpga.sch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]
2019-01-08 Improved tx sheet and corresponding documentation.
    [fpga.sch, if.sch, mixer.sch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]
2019-01-09 Improved documentation and parts of the schematic.
    [adc.sch, fmcw.sch, fpga.sch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]
2019-01-11 Changed components to official libs.
    [adc.sch, fmcw.sch, fpga.sch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]
2019-01-12 Finished design, began routing.
    [adc.sch, fmcw.kicad_pcb, fmcw.sch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]
2019-01-13 Placed most major components.
    [fmcw.kicad_pcb, fmcw.sch, rx.sch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]
2019-01-14 Completed clock placement and routing.
    [adc.sch, fmcw.kicad_pcb, fmcw.sch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]
2019-01-15 Place/route for ft2232h.
    [adc.sch, fmcw.kicad_pcb, fmcw.sch]
2019-01-15 Fixed transmission line width.
    [fmcw.kicad_pcb, fmcw.sch, if.sch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]
2019-01-15 Added test points.
    [fmcw.kicad_pcb]
2019-01-16 Completed FPGA bypassing.
    [fmcw.kicad_pcb, fpga.sch, mixer.sch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]
2019-01-16 Placed/routed all FPGA external components.
    [fmcw.kicad_pcb]
2019-01-16 Better MFNs for RF DC blocking caps.
    [adc.sch, fmcw.kicad_pcb, if.sch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]
2019-01-16 Completed transmitter placement/routing.
    [fmcw.kicad_pcb, mixer.sch, rx.sch]
2019-01-17 Completed receivers.
    [adc.sch, fmcw.kicad_pcb, mixer.sch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]
2019-01-17 Finished placing.
    [fmcw.kicad_pcb]
2019-01-17 Passes DRC.
    [fmcw.kicad_pcb, tx.sch]
2019-01-17 Completed power plane.
    [fmcw.kicad_pcb]
2019-01-17 Replaced relevant footprints for thermal via variety.
    [adc.sch, fmcw.kicad_pcb, if.sch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]
2019-01-18 Improved silkscreen appearance.
    [fmcw.kicad_pcb, fpga.sch]
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2019-01-24 Documentation improvements and spice simulations.
    [if-filter.sch]
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2019-02-24 Added Makefiles to facilitate running code. Reorganized code.
    [interface.cfg, program_flash.cfg, program_fpga.cfg]
2019-02-24 Add buffer amp for power amp reference voltage.
    [adc.sch, fmcw.kicad_pcb, fmcw.sch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]
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2019-02-28 Add RF antenna switch.
    [RF_Switch.sch, adc.sch, antenna_switch.kicad_pcb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]
2019-08-10 Unoptimized, working FFT
    This commit is a huge abuse of git, I know...
    [adc.sch, fmcw.kicad_pcb, fmcw.sch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]
2019-09-27 Huge, messy commit before I begin replacing FPGA code
    [RF_Switch.sch, antenna_switch.kicad_pcb, antenna_switch.sch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]
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2019-10-05 Fix FFT power computation when reading bytes
2019-10-06 Replace adc.v with ltc2292.v
    This uses a dedicated libdigital interface in
    place of the old adc.v interface.
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2019-11-05 reorganize project and create synthesizable top level
    [interface.cfg, program_flash.cfg, program_fpga.cfg]
2019-11-08 top verilog: replace ram with fifo
    Between filter and fft
2019-11-14 better control logic
    The FPGA control logic is now more tightly
    regulated so we don't process data between
    frequency ramps, for instance. This is all placed
    in a dedicated module.
    [plot.py, read.c]
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2019-12-11 software: communicate with python as subprocess
    This is a major overhaul of the previous PC code configuration. There
    are 2 major changes:
    1. Allow any breakdown of processing between PC and FPGA. The PC can
    also optionally skip steps (the FPGA currently cannot).
    2. Communicate with the Python plotting code as a subprocess of the C
    code. The python process is started as an unnamed pipe and data is
    sent to it via stdin. Data is no longer written to the filesystem,
    although this might be added as an additional option for debugging
    purposes.
    [plot.py]
2019-12-11 software: fix FFT hist plotting and other bug fixes
    [plot.py]
2019-12-12 gateware: fix window module
    [plot.py]
2019-12-12 gateware: move source files
    [interface.cfg, program_flash.cfg, program_fpga.cfg]
2019-12-19 cad: add antenna mount
    [antenna-mount.scad]
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2020-01-03 pcb: connect ADC reference to voltage supply rail
    [adc.sch, fmcw.kicad_pcb, fmcw.sch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]
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2020-02-03 move main pcb hardware to boards+version subdirectory
    [adc.sch, fmcw.kicad_pcb, fmcw.sch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]
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2020-02-24 fix fir bug related to improper normalization factor
    [fir.py, fir.v, plot.py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]
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2020-04-16 rev2 pcb: basic receiver layout done
    [adc.sch, fmcw.kicad_pcb, fmcw.sch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]
2020-04-16 pcb: angle mixer baluns to reduce balanced line length
    [fmcw.kicad_pcb]
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2020-04-28 revert to kicad v5 for pcb gen
    V6 contains a few bugs and a V6 board cannot be edited with V5.
    [adc.sch, clock.sch, fmcw.kicad_pcb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]
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2020-04-28 replace v5 footprints
    [fmcw.kicad_pcb]
2020-04-30 finish placement and routing
    [adc.sch, clock.sch, fmcw.kicad_pcb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]
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2020-05-08 add sample averaging
    Averaging pertains to the samples after they have passed through the
    FIR. This is intended to improve the SNR since noise should be
    randomly distributed.
    [fir.v, top.v]
2020-05-12 ftdi stream test
    Initial working version with 0% dropout and roughly 45MB/s
    throughput.
    [interface.cfg, program_fpga.cfg]
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2020-05-20 add almost full and almost empty fifo flags
    Most data (using a 40MHz clock) now makes it to the PC intact; only
    0.07% is dropped. This corresponds to attempted writes to the FT2232H
    when the txe line is low.
    [program_fpga.cfg]
2020-05-22 add beta directory for future gateware
    [interface.cfg, program_fpga.cfg]
2020-05-23 verilog raw impl now consitently sends all bytes but 1
    The byte missing is the last one. I'm having trouble locating the
    source of this bug. Otherwise, though, the module now works quite
    well. The reads are consistent and the start and stop sequences are
    only sent once.
    [read.c, top.v]
2020-05-28 data transmission is correctly aligned but inconsistent
    [top.v]
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2020-05-28 txe now correctly handled
    [plot.py, read.c, top.v]
2020-06-04 switch ftclk to MRCC pin and place silkscreen
    [fmcw.kicad_pcb, fpga.sch, rx.sch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]
2020-06-17 plotting from fpga raw data works
    [board.cfg, horn-antenna-half.scad, interface.cfg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]
2020-06-18 gateware: fix top module to send last sample
    Previous implementation sent 1 less than the full sequence.
    [top.v]
2020-06-18 initial implementation of python-only host pc code
    This implementation creates a basic shell environment for user
    configuration options and retrieves data and logs it. Plotting is not
    yet implemented.
    Restricting host PC code to python rather than python + C code (where
    C code reads data from the device) simplifies the logic significantly
    at the expense of slower reads. The slower reads may not be an issue
    since the plotting is the major bottleneck anyway. However, if the
    python-implemented reading does prove to be too slow it should be
    possible to implement the reading in multithreaded
    C (producer-consumer) and tie it into Python with Cython. In any
    event, it makes more sense to call the C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
    [fmcw.py]
2020-06-19 plotting mostly works but is too slow
    [fmcw.py]
2020-06-19 pc software: fix data type length computations
    [fmcw.py]
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2020-06-25 fix subtract last string display
    [fmcw.py]
2020-06-25 gateware: replace lsb with pll_sync_ctr
    [top.v]
2020-06-26 software: fix computed sweep length of fir data
    [fmcw.py]
2020-06-26 gateware: parameterize flip-flop synchronizer number of stages
2020-06-26 gateware: remove fir reset
    [fir.v, top.v]
2020-06-26 gateware: remove window reset
    [top.v]
2020-06-27 gateware: remove fft reset
    [top.v]
2020-06-27 gateware adf4158.v: fix state machine initialization
    [adf4158.v]
2020-06-28 gateware: add asynchronous reset to processing modules
    This simply clears the valid pipeline and prevents invalid data from
    appearing as valid if the data processing pipeline is used soon after
    asserting a reset.
    [fir.v, top.v]
2020-06-28 gateware: live reconfiguration, including output data supported
    This is an initial implementation of a fully reconfigurable design. By
    fully reconfigurable, I mean that the FPGA waits for configuration
    data from the host PC and then is able to send any output data and
    supports any configuration of the frequency synthesizer. However, the
    design is not yet tested (and therefore likely contains bugs) and the
    PC code to support it has not yet been written.
    [adf4158.v, top.v]
2020-07-06 gateware fft: don't time-multiplex twiddle multiply
    Using separate multipliers for the twiddle multiplication allows
    timing to succeed. This would also allow the fft module to be used at
    a higher clock rate if we needed that. This comes at a significant
    future cost, however. Namely, the fft module now requires 3x the
    number of DSP elements it needed previously. This will prevent the use
    of an additional FFT if we want to perform an angle calculation
    later (unless, potentially we are able to reuse the FFT module). It
    should be possible at some later time to go back to sharing the DSP
    element, since for some reason this worked in a previous
    implementation. This will probably just require some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
    [top.v]
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2020-07-08 gateware top: change parameter initial values
    The setting mechanism doesn't work for this, and so they must be
    initialized correctly. This, of course, is an obvious potential source
    of bugs.
    [top.v]
2020-07-09 gateware top: fix state machine in case that ft reads must be done in advance
    [top.v]
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2020-07-11 gateware top: fix simulation
    This simulation is unfortunately less flexible than the previous
    one. The FT2232H RX FIFO buffer acts like it doesn't have an output
    register. This means I can't use my existing FIFO to simulate it. We
    could create a custom FIFO for this, but that seems like overkill at
    the moment.
    [top.v]
2020-07-11 software: correct bit lengths
    [fmcw.py]
2020-07-12 all intermediate processing steps can now be sent from fpga to pc
    FFT data is not yet in bit-normal order (currently bit reversed).
    [fmcw.py, top.v]
2020-07-12 software: add bit reversal for fft fpga data
    This could be done simply on the FPGA for greater efficiency, but
    numpy does a good job at it and the end user wouldn't notice a
    performance difference.
    [fmcw.py]
2020-07-14 gateware: correct flag counter width
    [top.v]
2020-07-14 gateware adf4158: remove no longer necessary parameterization
    Configuration is now controlled by host PC.
    [adf4158.v]
2020-07-15 gateware top: fix tx issue when txe deasserted
    The FPGA now sends all data correctly when TXE goes to 1 during a
    transmission.
    [top.v]
2020-07-16 perform FFT bit reversal on FPGA
    [fmcw.py, top.v]
2020-07-21 gateware fir: fix enable and latency
    The FIR module takes longer to flush all values from its internal
    registers than its data output latency. When the first inputs are
    registered, it expects most of its internal registers to be
    untouched (left with a value of 0). This change keeps these registers
    0 until enable is asserted, at which point the registers begin to
    fill.
    This also solves a related issue with the latency. The correct latency
    is actual 1 clock enable cycle instead of 2. The previous use of 2 was
    a false positive believe because of the above mentioned issue.
    [fir.v, top.v]
2020-07-21 gateware: fix number tx samples for new fir enable functionality
    [top.v]
2020-07-21 gateware fft: fix data correctness for repeat sweeps
    Previously, the stage counters did not return to 0 after a full fft
    input and output. This created incorrect output data. That issue is
    now resolved.
2020-07-22 replace old gateware and software dirs with beta dirs
    [board.cfg, interface.cfg, program_flash.cfg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]
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2020-07-29 software: normalize FFT so that dB values are correct
    [fmcw.py]
2020-08-08 pcb: small changes to rev2
    [fmcw.kicad_pcb]
2020-08-08 if amplifier ngspice sim: fix positive rail voltage
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2020-08-29 remove spi bit generation
    This does not work.
2020-08-29 disable fir plot
    This seems to be due to some bug in nixpkgs matplotlib.
    [fir.py]
2020-08-29 add cad stl files
    [antenna-mount.stl, horn-antenna.stl]
2020-09-03 add rev2b and migrate rev2 -> rev2a
    rev2b will be a more space-efficient version of rev2a, whose board
    cost of $150 is significantly more than henrik's original board. The
    rev2b PCB should cost around $110.
    Also fixes #1 by using MX25L3233F as the FPGA flash memory.
    [adc.sch, clock.sch, fmcw.kicad_pcb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]
2020-09-10 software: minor fft scaling fix
    [fmcw.py]
2020-09-11 rev2b pcb: replace wilkinson divider with power splitter
    Closes #4.
    [fmcw.kicad_pcb, rx.sch, tx.sch]
2020-09-12 rev2 pcb: finish routing traces
    [clock.sch, fmcw.kicad_pcb, fpga.sch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]
2020-09-12 rev2 pcb: place via fences
    [fmcw.kicad_pcb]
2020-09-13 rev2 pcb: add via fences and stitching
    [fmcw.kicad_pcb]
2020-09-14 rev2b: add return path vias
    [fmcw.kicad_pcb]
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2020-09-14 rev2b: add via perimeter
    [fmcw.kicad_pcb]
2020-09-14 rev2b: update pcb cost dwg
    [fmcw.kicad_pcb]
2020-09-14 rev2b: add board title silkscreen
    [fmcw.kicad_pcb]
2020-09-20 rev2b: add soldermask back to transmission lines
    This is a tough choice. ENIG isn't much better than soldermask
    apparently and at least we get extra protection with soldermask.
    [fmcw.kicad_pcb]
